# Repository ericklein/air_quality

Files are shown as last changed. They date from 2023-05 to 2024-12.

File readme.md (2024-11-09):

# Air Quality
AI: PUT HERO SHOT HERE

## Purpose
Air Quality, aka AQ, captures temperature, humidity, and if configured with the appropriate sensor, CO2 (carbon dioxide) values. If AQ is configured with a screen, it can display this information. If AQ is connected to WiFi, it can log this information to a number of network endpoints, and it displays local outdoor weather and air quality information to compliment the indoor sensor information.

AQ was created to determine if the CO2 level in the room was "good" and grew into a fuller featured room air quality monitor.

## Associated projects
AQ has a number of sibling projects that share common hardware and code attributes:
- [Powered Air Quality](https://github.com/ericklein/powered_air_quality) has all of the features of AQ along with the ability to sample local air particulate levels. This project uses an AC power source.
- [RCO2](https://github.com/ericklein/rco2) is a small, portable version of AQ that only samples and displays air quality levels.
- [Badge](https://github.com/ericklein/badge) is RCO2 in a badge form factor capable of displaying additional information beyond air quality levels.

## Features
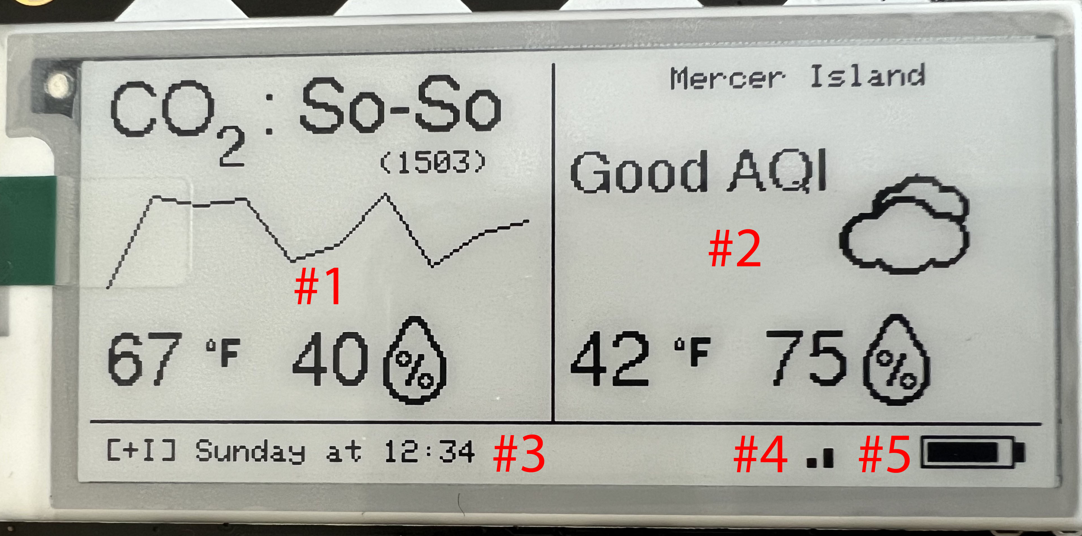
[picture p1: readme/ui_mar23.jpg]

### Indoor air quality information (#1)
- If available, displays the US standard CO2 label and value
- Displays the temperature and humidity
### Outside air quality information (#2)
- Uses OpenWeatherMap data, if available, to display
	- latest air quality information
	- current weather condition as icon
	- temperature and humidity levels
### Data publishing information (#3)
- displays the last time the screen information was updated.
- [+I] the indoor temperature, humidity, and CO2 information was successfully published to the defined InfluxDB server
- [+M] the indoor temperature, humidity, and CO2 information was successfully published to the defined MQTT broker
### WiFi signal strength (#4)
- based on RSSI
### Battery level (#5)

## Target configuration
- Set parameter configuration using config.h
- Private configuration settings including WiFi SSID/password and network endpoint credentials are contained in a `secrets.h` file that is not included in this repo.  Instead you'll find the file `secrets_template.h`, which should be copied to `secrets.h` and then edited to supply the right access credentials and configuration values to match your deployment environment.

## Bill of Materials (BOM)
### MCU
- [Adafruit MagTag](https://www.adafruit.com/product/4800)
- [Adafruit ESP32V2 Feather](https://www.adafruit.com/product/5400)
	- core code is fairly portable
### WiFi
- [Adafruit MagTag](https://www.adafruit.com/product/4800)
	- any ESP32
### Sensors
- [AHT20 temp/humidity sensor](https://www.adafruit.com/product/4566)
	- or similar AHT20 parts
- [BME280 temp/humidity sensor](https://www.adafruit.com/product/2652)
- [SCD40 temp/humidity/CO2 sensor](https://www.adafruit.com/product/5187)
	- SCD40 used in most of our build configurations
	- can use any SCD40 connected over i2c
### Battery
#### monitor
- [LC709203F battery voltage monitor](https://www.adafruit.com/product/4712)
- [GPIO pin on ESP32V2 Feather](https://www.adafruit.com/product/5400)
#### battery
- standard LiPo battery with JST 2-PH cable
### Screen
- [Adafruit MagTag (EPD)](https://www.adafruit.com/product/4800)
- [Adafruit 2.9" E-Ink Featherwing](https://www.adafruit.com/product/4777)
### Buttons/Switches
- [Adafruit MagTag](https://www.adafruit.com/product/4800)
	- on/off switch
### Pinouts
- SCD40
    - Stemma QT cable between MCU board and SCD40 board
        - or connect 3.3v/5v, GND, SDA, SCL on both sides
- LC709203F
    - Stemma QT cable between MCU board and SCD40 board
        - or connect 3.3v/5v, GND, SDA, SCL on both sides
## Supported network endpoints
### MQTT
- uncomment #define MQTT in config.h
- set appropriate parameters in config.h and secrets.h
	- Technical References
		- https://hackaday.com/2017/10/31/review-iot-data-logging-services-with-mqtt/
### Hassio MQTT
- AI: ADD DOCUMENTATION
### InfluxDB
- AI: ADD DOCUMENTATION
### DWEET
- AI: ADD DOCUMENTATION

## Issues and Feature Requests
- [Github Issues](https://github.com/ericklein/air_quality/issues)

## .plan (big ticket items)
- [WiFI Manager](https://github.com/tzapu/WiFiManager) support
- OTA firmware update support
- Change hardware to non ESP32S2 MCU, allowing multiple GPIO pin wakeup, which enables button presses to cycle through multiple information screens
## Supporting Material
### Screen
- Good Display SPI; GDEW029T5D 2.9" b/w 128x296, UC8151D 
- https://cdn-learn.adafruit.com/downloads/pdf/adafruit-gfx-graphics-library.pdf
### Battery
- [LC709203F datasheet](readme/LC709203F_datasheet.pdf)
### Temperature and Humdity
- [Ideal indoor humidity](https://iaq.works/humidity/indoor-humidity-level-why-is-the-40-60-range-ideal/)
### CO2 (Carbon Dioxide)
#### Scales
We currently use the following scale:
- <800 - Good
- 800-999 - So-So
- 1000+ - Poor
##### Alternate ideas
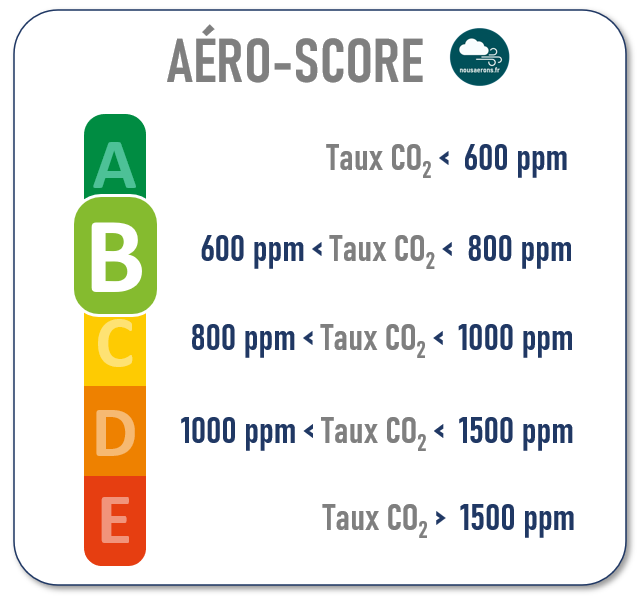
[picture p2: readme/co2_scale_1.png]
Example 1
- 
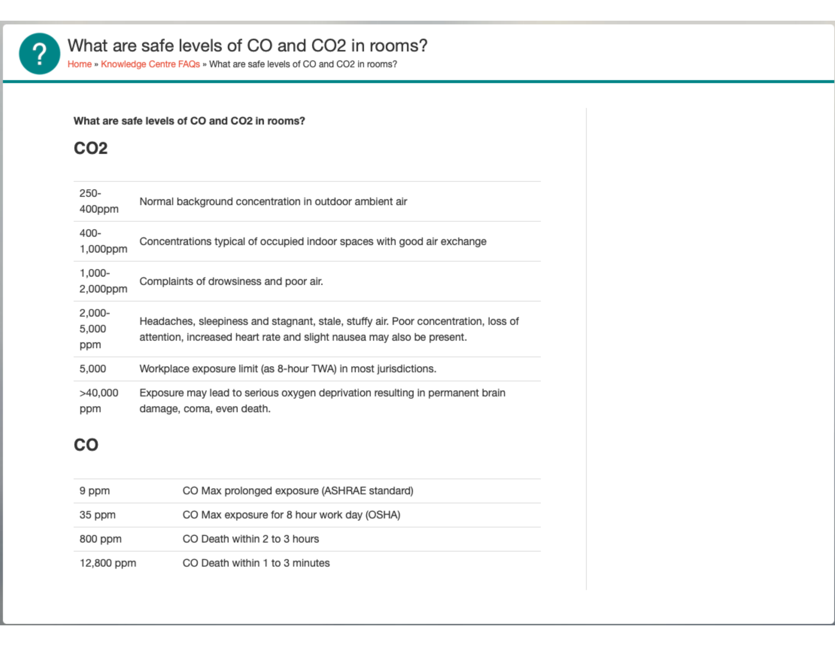
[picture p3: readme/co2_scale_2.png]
Example 2
- 
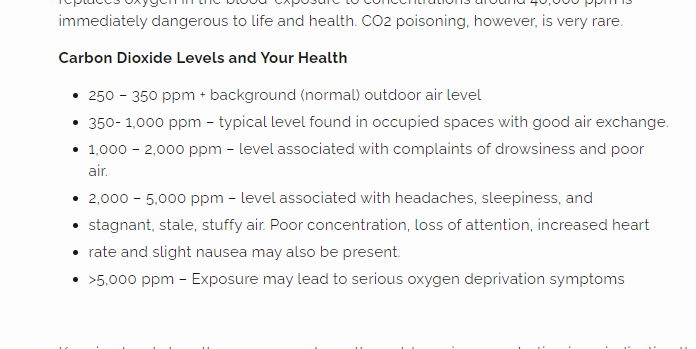
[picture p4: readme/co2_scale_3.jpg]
Example 3
- 
#### Impact on health
- [CO2 and indoor air quality](readme/CO2_and_indoor_air_quality.pdf)
#### Sensors
- [AHT20 info](https://learn.adafruit.com/adafruit-aht20)
- [CO2 sensor types](https://www.airgradient.com/blog/co2-sensors-photo-acoustic-vs-ndir-updated/)
- SCD40 sensor
	- [SCD40 datasheet](readme/Sensirion_CO2_Sensors_SCD4x_Datasheet.pdf)
### AQI
- [AQI Overview](readme/aqi_overview.md)
- [Open Weather Map Air Pollution API](https://openweathermap.org/api/air-pollution)
- [OSHA Air Quality](readme/OSHA_Indoor_Air_Quality.pdf)
- [Great site for air quality info](https://itsairborne.com/)
- [NYT on indoor gas stoves](https://www.nytimes.com/2023/01/29/climate/gas-stove-health.html)

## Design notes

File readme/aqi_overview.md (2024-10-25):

# Air Quality Index (AQI) overview
It's worth noting that while most people have heard of an "Air Quality Index" from their local weather service or news, the calculation of AQI from sensor readings is less well known.  Sensors measure and report particulate concentrations in various size ranges, the most widely used of which is "PM2.5", meaning airborne particulates of 2.5 microns in diameter or smaller, measured in micrograms per cubic meter.  
The more particulates measured the worse the air quality and, eventually, the greater the danger to humans and animals.  Howeveer, the perceived quality of the air and the risk from exposure vary in a non-obvious way based on the actual PM2.5 values observed.
That variability is what gave rise to the idea of an Air Quality Index in the first place, though as is often the case in associating health factors and risk with environmental data different governing bodies and standards organizations have put forward different ways of calculating risk from sensor data.  You can read much more about this in the Wikipedia page for [Air Quality](https://en.wikipedia.org/wiki/Air_quality_index).
In the US, the Environmental Protection Agency (EPA) developed its own AQI measure, dividing the normal range of measured particulates and pollutants into six categories indicating increased levels of health concerns.  An overall AQI value is calculated from a piecewise linear function, with scaling and transition points defined by the EPA.  More details on that math are shared in the Wikipedia page cited above, as well as this [post](https://forum.airnowtech.org/t/the-aqi-equation/169) on the AirNow tech forum.

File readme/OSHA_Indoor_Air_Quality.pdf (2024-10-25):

# Indoor Air Quality in Commercial and Institutional Buildings

OSHA 3430-04 2011

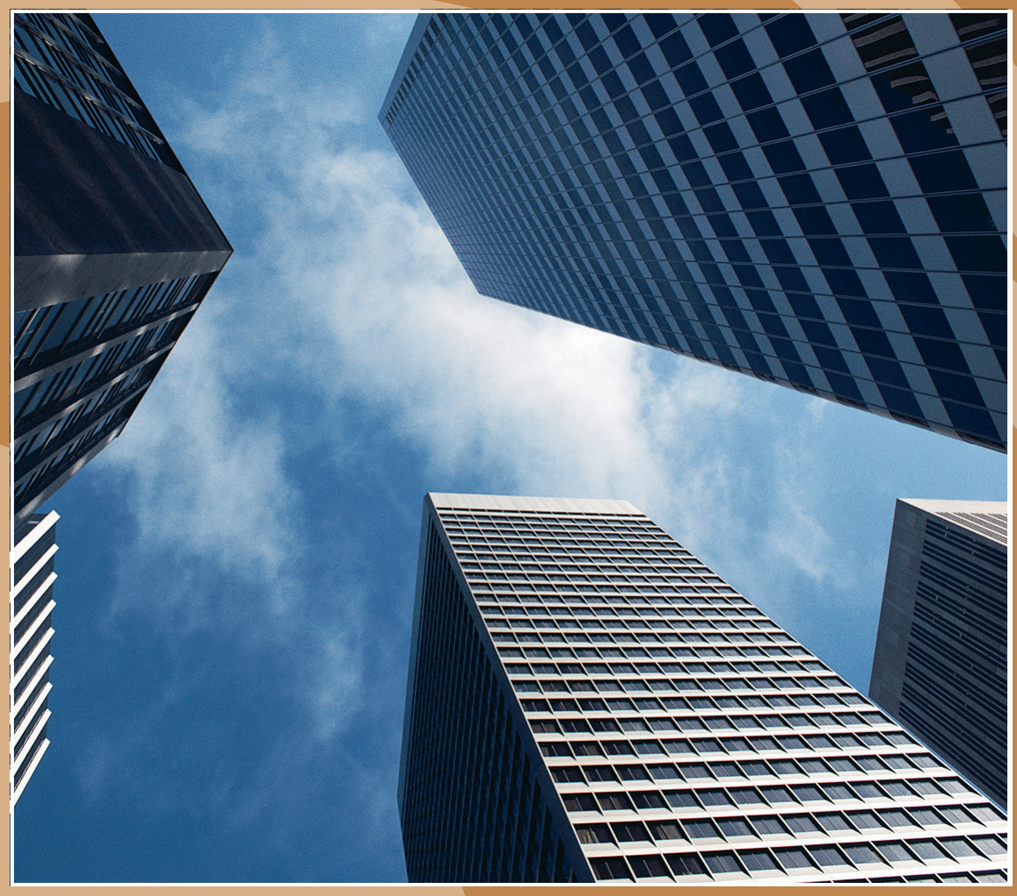
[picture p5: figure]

### Occupational Safety and Health Act of 1970

“To assure safe and healthful working conditions for working men and women; by authorizing enforcement of the standards developed under the Act; by assisting and encouraging the States in their efforts to assure safe and healthful working conditions; by providing for research, information, education, and training in the field of occupational safety and health.”

This publication provides a general overview of a particular standards-related topic. This publication does not alter or determine compliance responsibilities which are set forth in OSHA standards, and the Occupational Safety and Health Act of 1970. Moreover, because interpretations and enforcement policy may change over time, for additional guidance on OSHA compliance requirements, the reader should consult current administrative interpretations and decisions by the Occupational Safety and Health Review Commission and the courts.

Material contained in this publication is in the public domain and may be reproduced, fully or partially, without permission. Source credit is requested but not required.

This information will be made available to sensoryimpaired individuals upon request. Voice phone:
(202) 693-1999; teletypewriter (TTY) number: 1-877-889-5627.

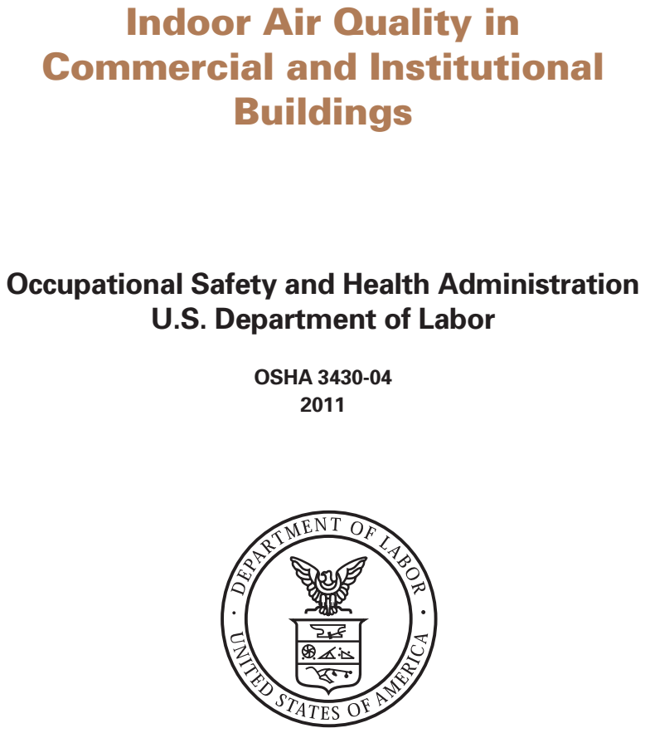
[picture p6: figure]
Indoor Air Quality in Commercial and Institutional Buildings; U.S. Department of Labor; OSHA 3430-04 2011

## Occupational Safety and Health Administration

The guidance is advisory in nature and informational in content. It is not a standard or regulation, and it neither creates new legal obligations nor alters existing obligations created by OSHA standards or the Occupational Safety and Health Act. Pursuant to the OSH Act, employers must comply with safety and health standards and regulations issued and enforced by either OSHA or by an OSHA-approved State Plan. In addition, the Act’s General Duty Clause, Section 5(a)(1), requires employers to provide their workers with a workplace free from recognized hazards likely to cause death or serious physical harm.

## Contents

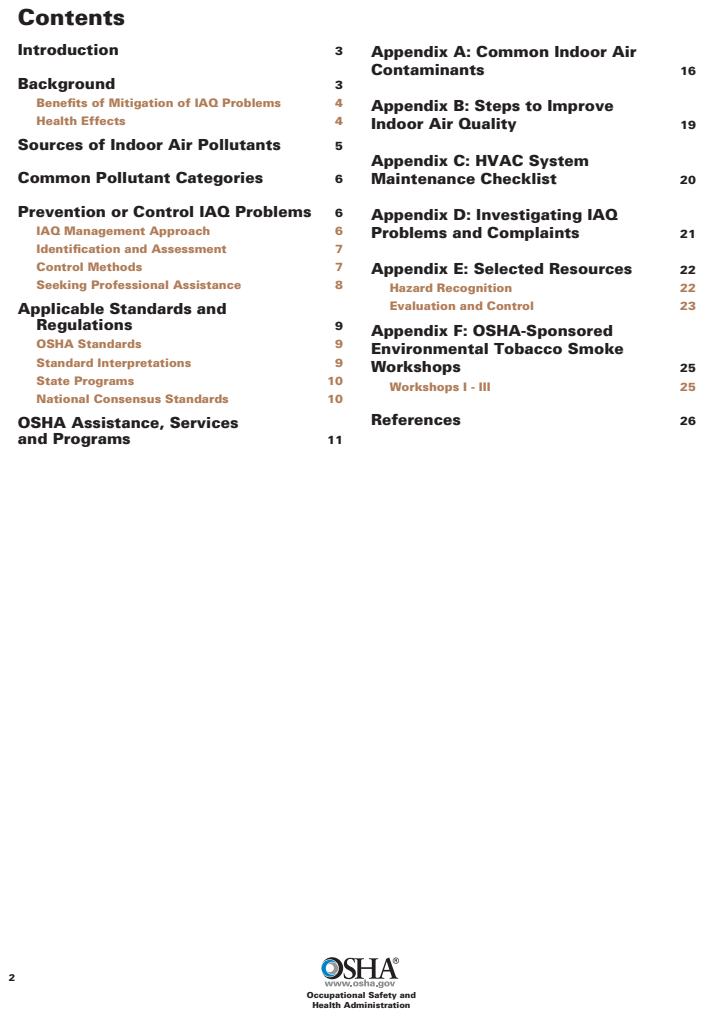
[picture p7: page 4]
Introduction; Background; Benefits of Mitigation of IAQ Problems; Health Effects; Sources of Indoor Air Pollutants; Common Pollutant Categories; Prevention or Control IAQ Problems; IAQ Management Approach; Identification and Assessment; Control Methods; Seeking Professional Assistance; Regulations; OSHA Standards; Standard Interpretations; State Programs; National Consensus Standards; and Programs; Contaminants; Indoor Air Quality; Maintenance Checklist; Problems and Complaints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

Applicable Standards and
OSHA Assistance, Services

Appendix A: Common Indoor Air

Appendix B: Steps to Improve

Appendix C: HVAC System

Appendix D: Investigating IAQ

Appendix F: OSHA-Sponsored
Environmental Tobacco Smoke

Occupational Safety and
Health Administration

INDOOR AIR QUALITY IN COMMERCIAL AND INSTITUTIONAL BUILDINGS | 3

## Introduction

Indoor air quality (IAQ) is a major concern to businesses, schools, building managers, tenants, and workers because it can impact the health, comfort, well-being, and productivity of the building occupants. OSHA recognizes that poor IAQ can be hazardous to workers’ health and that it is in the best interest of everyone that building owners, managers, and employers take a proactive approach to address IAQ concerns.

This OSHA guidance document on IAQ provides practical recommendations that will help prevent
or minimize IAQ problems in commercial and institutional buildings, and help resolve such problems quickly if they do arise. It provides flexible guidance to employers to help them keep their buildings free of pollutants or conditions that lead
to poor IAQ. It also provides information on good IAQ management, including control of airborne pollutants, introduction and distribution of adequate make-up air, and maintenance of an acceptable temperature and relative humidity. Temperature and humidity are important because thermal comfort underlies many complaints about “poor air quality.” Some of the information presented here has been derived from the Environmental Protection Agency’s (EPA) report, “An Office Building Occupant’s Guide to IAQ” (1)¹ and other documents listed in Appendix E, Selected Resources. The issue of environmental tobacco smoke will only be addressed in Appendix F, or indirectly in discussions of air quality relative to some possible components of tobacco smoke, e.g., carbon monoxide, carbon dioxide, particulates, etc. In 1998, OSHA conducted a series of three workshops on this issue and the proceedings of these workshops were published in 1999. See Appendix F for more information.

This document is directed primarily at employers, building owners and managers, and others responsible for building maintenance, but may also be used as a basic reference for all those involved in IAQ issues. Furthermore, information presented here can help with the decision of whether or not the services of an outside professional may be needed. The advice of a medical professional should always be sought if there are any immediate health issues. Contractors and other professionals (e.g., industrial hygienists or other environmental health and safety professionals) who respond to IAQ concerns, as well as members of the general public, may also find this information helpful.

## Background

IAQ has been identified by the EPA as one of the top five most urgent environmental risks to public health (2). The Centers for Disease Control and Prevention (CDC) estimates that the majority of Americans spend approximately 90 percent of their time indoors (3). On average, office workers spend approximately 40 hours a week in office buildings. These workers also study, eat, drink, and, in certain work settings, sleep in enclosed environments where make-up air (i.e., fresh air added to recirculated air) may be compromised. For this reason, some experts believe that more people may suffer from the effects of indoor air pollution than from outdoor air pollution.

Each building has its own set of circumstances. Air quality may be determined by the site of the building, its original design, renovations, whether air handling systems have been maintained, occupant densities, activities conducted within the building, and the occupants’ satisfaction with their environment. IAQ problems can arise from a single source or any combination of factors. Inadequate IAQ may begin with poor building design or failure of the building enclosure or envelope (roof, facade, foundation, etc.). Other issues may be associated with the location of the building and mixed uses of the building. Many common IAQ problems are associated with improperly operated and maintained heating, ventilating and air-conditioning (HVAC) systems, overcrowding, radon, moisture incursion and dampness, presence of outside air pollutants, and the presence of internally generated contaminants such as use of cleaning and disinfecting supplies and aerosol products, off-gassing from materials in the building, and use of mechanical equipment. Improper temperature and relative humidity conditions can also present problems, especially concerning comfort.

Many IAQ complaints are associated with flaws in building design and by inadequate routine preventive maintenance of building enclosures (envelopes), plumbing, and HVAC systems (2, 4, 5). To resolve many IAQ problems, a preventive maintenance program should be established based on the system’s recommended maintenance schedule outlined by the architect or engineer, the manufacturer, or an HVAC professional. Regular preventive maintenance not only ensures that systems are operating properly, but also can result in cost savings, improved operating efficiency, and
increased worker productivity (6). The U.S. Green ¹The numbers in parentheses refer to specific entries in the last section of this document titled “References.”

4

Research has linked building dampness with significant health effects. Numerous species of bacteria and fungi, in particular filamentous fungi (mold), can contribute significantly to indoor air pollution (4, 15-20). Whenever sufficient moisture is present within workplaces, these microbes can grow and affect the health of workers in several ways. Workers may develop respiratory symptoms, allergies, or asthma (8). Asthma, cough, wheezing, shortness of breath, sinus congestion, sneezing, nasal congestion, and sinusitis have all been associated with indoor dampness in numerous studies (21-23). Asthma is both caused by and worsened by dampness in buildings. The most effective means to prevent or minimize adverse health effects is to determine the sources of persistent dampness in the workplace and eliminate them. More details on preventing mold-related problems can be found in the OSHA publication titled: “Preventing Mold-Related Problems in the Indoor Workplace” (17). Other environmental factors such as poor lighting, stress, noise, and thermal discomfort may cause or contribute to these health effects (8).

Building Council (USGBC), among others, has demonstrated that IAQ issues can be readily and practically addressed when building systems are retrofitted for energy efficiency. (http://www.usgbc.org/
DisplayPage.aspx?CMSPageID=221#v2008)
Benefits of Mitigation of IAQ Problems Good IAQ in buildings is an important component of a healthy indoor environment. It contributes to a favorable and productive environment for building occupants, giving them a sense of comfort, health, and well-being. Significant increases in worker productivity have also been demonstrated when the air quality was adequate (6). Research has also shown that workers in buildings with adequate air quality have reduced rates of symptoms related to poor air quality (7).

Health Effects
Symptoms related to poor IAQ are varied depending on the type of contaminant. They can easily be mistaken for symptoms of other illnesses such as allergies, stress, colds, and influenza. The usual clue is that people feel ill while inside the building, and the symptoms go away shortly after leaving the building, or when away from the building for a period of time (such as on weekends or a vacation). Health or symptom surveys, such as the one included in Appendix D, have been used to help ascertain the existence of IAQ problems.

Failure of building owners and operators to respond quickly and effectively to IAQ problems can lead to numerous adverse health consequences. Health effects from indoor air pollutants may be experienced soon after exposure or, possibly, years later (8, 9, 10). Symptoms may include irritation of
the eyes, nose, and throat; headaches; dizziness; rashes; and muscle pain and fatigue (11, 12, 13, 14). Diseases linked to poor IAQ include asthma and hypersensitivity pneumonitis (11, 13). The specific pollutant, the concentration of exposure, and the frequency and duration of exposure are all important factors in the type and severity of health effects resulting from poor IAQ. Age and preexisting medical conditions such as asthma and allergies may also influence the severity of the effects. Long-term effects due to indoor air pollutants may include respiratory diseases, heart disease, and cancer, all of which can be severely debilitating or fatal (8, 11, 13).

INDOOR AIR QUALITY IN COMMERCIAL AND INSTITUTIONAL BUILDINGS | 5

Renovation Activities: When painting and other renovations are being conducted, dust or other by-products of the construction materials are sources of pollutants that may circulate through a building. Isolation by barriers and increased ventilation to dilute and remove the contaminants are recommended.

Local Exhaust Ventilation: Kitchens, laboratories, maintenance shops, parking garages, beauty and nail salons, toilet rooms, trash rooms, soiled laundry rooms, locker rooms, copy rooms and other specialized areas may be a source of pollutants when they lack adequate local exhaust ventilation.

Building Materials: Disturbing thermal insulation or sprayed-on acoustical material, or the presence of wet or damp structural surfaces (e.g., walls, ceilings) or non-structural surfaces (e.g., carpets, shades), may contribute to indoor air pollution.

Building Furnishings: Cabinetry or furniture made of certain pressed-wood products may release pollutants into the indoor air.

Building Maintenance: Workers in areas in which pesticides, cleaning products, or personal-care products are being applied may be exposed to pollutants. Allowing cleaned carpets to dry without active ventilation may promote microbial growth.

Occupant Activities: Building occupants may be the source of indoor air pollutants; such pollutants include perfumes or colognes.

## Sources of Indoor Air Pollutants

The relative importance of any single source depends on how much of a given pollutant it emits, how hazardous those emissions are, occupant proximity to the emission source, and the ability of the ventilation system (i.e., general or local) to remove the contaminant. In some cases, factors such as the age and maintenance history of the source are significant.

Sources of indoor air pollution may include:

Building Site or Location: The location of a building can have implications for indoor pollutants. Highways or busy thoroughfares may be sources of particulates and other pollutants in nearby buildings. Buildings sited on land where there was prior industrial use or where there is a high water table may result in leaching of water or chemical pollutants into the building.

Building Design: Design and construction flaws may contribute to indoor air pollution. Poor foundations, roofs, facades, and window and door openings may allow pollutant or water intrusion. Outside air intakes placed near sources where pollutants are drawn back into the building (e.g., idling vehicles, products of combustion, waste containers, etc.) or where building exhaust reenters into the building can be a constant source of pollutants. Buildings with multiple tenants may need an evaluation to ensure emissions from one tenant do not adversely affect another tenant.

Building Systems Design and Maintenance: When the HVAC system is not functioning properly for any reason, the building is often placed under negative pressure. In such cases, there may be infiltration of outdoor pollutants such as particulates, vehicle exhaust, humid air, parking garage contaminants, etc.

Also, when spaces are redesigned or renovated, the HVAC system may not be updated to accommodate the changes. For example, one floor of a building that housed computer services may be renovated for offices. The HVAC system would need to be modified for office employee occupancy (i.e., modifying temperature, relative humidity, and air flow).

6

## Prevention and Control of IAQ Problems

IAQ Management Approach
Ideally, an employer should use a systematic approach when addressing air quality in the workplace. The components of a systematic approach for addressing IAQ are the same as those for an overall safety and health program approach, and include management commitment, training, employee involvement, hazard identification and control, and program audit. Management needs to be receptive to potential concerns and complaints, and to train workers on how to identify and report air quality concerns. If employees express concerns, prompt and effective assessment and corrective action is the responsibility of management.

It is recommended that building owners/managers develop and implement an IAQ management plan to address, prevent, and resolve IAQ problems in their specific buildings. The EPA’s report, IAQ Tools for Office Buildings, provides a set of flexible and specific activities that can be useful to building owners/managers for developing such a plan. A key feature of the plan is the selection of an IAQ Coordinator. The role and functions of an IAQ Coordinator are described in Section 3 of the EPA’s report, IAQ Tools for Schools Action Kit (24). Other critical features of the plan include establishing necessary IAQ policies, assessing the current status of IAQ in buildings through periodic inspections, maintaining appropriate logs and checklists, performing necessary repairs and upgrades, and implementing follow-up assessments or other needed actions.

Employers who lease space should be familiar with the building management’s program and methods for mitigating or resolving indoor air quality problems. It is especially important for employers to know who to contact in buildings where there is mixed use and pollutants are emanating from other sources in the building. Employers should negotiate leases that specify IAQ performance criteria. For example, a lease should specify that the space be ventilated with outdoor air while occupied and at a rate described in ASHRAE 62.1 Ventilation for Acceptable Indoor Air Quality.

An important management strategy is to foster a team approach for problem solving and consensus building. The IAQ Team should include, but not necessarily be limited to, building occupants, administrative staff, facility operators, custodians, building healthcare staff, contract service providers, and other interested parties.

## Common Pollutant Categories

Although there are numerous indoor air pollutants that can be spread through a building, they typically fall into three basic categories: biological, chemical, and particle (1).

Biological
Excessive concentrations of bacteria, viruses, fungi, dust mites, animal dander, and pollen may result from inadequate maintenance and housekeeping, water spills, inadequate humidity control, condensation, or water intrusion through leaks in the building envelope or flooding.

Chemical
Sources of chemical pollutants (gases and vapors) include emissions from products used in the building (e.g., office equipment; furniture, wall and floor coverings; pesticides; and cleaning and consumer products), accidental spills of chemicals, products used during construction activities such as adhesives and paints, and gases such as carbon monoxide, formaldehyde, and nitrogen dioxide, which are products of combustion.

Particle (Non-biological)
Particles are solid or liquid, non-biological, substances that are light enough to be suspended in the air. Dust, dirt, or other substances may be drawn into the building from outside. Particles can also be produced by activities that occur in buildings such as construction, sanding wood or drywall, printing, copying, and operating equipment.

Some of the most common indoor air pollutants, and the means to control or prevent them, are discussed in Appendix A.

INDOOR AIR QUALITY IN COMMERCIAL AND INSTITUTIONAL BUILDINGS | 7

the effectiveness of ventilation (5, 26), and excessive population density (e.g., overcrowding).
- Ensure that good housekeeping practices are being applied.
- Ensure that routine preventive maintenance and upkeep of buildings is being performed. A preventive maintenance program provides the care to all building systems and components that keeps them operating at peak performance according to manufacturer’s specifications, and also allows for early detection of problems
(1, 18).
- Ensure that scheduled renovations are isolated from the building’s general dilution ventilation system when occupants are in the building. Control Methods
There are three basic control methods for lowering concentrations of indoor air pollutants:

### 1. Source management

Source management includes removal, substitution, and enclosure of sources. It is the most effective control method when it can be applied practically. For example, the U.S. Consumer Product Safety Commission recommends installing carpets that are low-volatile organic compound (VOC) emitters, and encourages consumers to ask retailers or installers about the carpet industry’s voluntary “green label” program for new carpets (27). According to the carpet industry, the green and white logo displayed on carpet samples informs the consumer that the specific manufacturer’s product has been tested by an independent laboratory and has met the criteria for very low emissions (28). The label, however,
is not a guarantee that the carpet will not cause health problems (27). Another example is that the employer can set up temporary barriers or place the space under negative pressure relative to adjoining areas to contain the pollutants during construction activities.

### 2. Engineering controls

a. Local exhaust
Local exhaust, such as a canopy hood, is very effective in removing point sources of pollutants before they can be dispersed into the building’s indoor air.
b. General dilution ventilation
General dilution ventilation systems, when properly designed, operated, and maintained, will control normal amounts of air pollutants.
A well-designed and functioning HVAC system controls temperature and relative humidity levels

Lastly, following up with affected personnel will serve to validate the effectiveness of the mitigation activities. For more information about the IAQ management approach, refer to OSHA’s Safety and Health Topics Page on Injury and Illness Prevention Programs. (http://www.osha.gov/dsg/topics/safetyhealth/index.html).
Identification and Assessment
Methods used in an IAQ investigation may include identifying pollutant sources, evaluating the HVAC system performance, observing production processes and work practices, measuring contamination levels and employee exposures, providing medical testing or physical examinations, conducting employee interviews, and reviewing records of medical tests, job histories, and injuries and illnesses. The Appendices provide resources and checklists that building owners, managers, and occupants can use to investigate IAQ complaints, document walkthrough inspections, and correct IAQ problems.

To prevent IAQ problems effectively and efficiently, building managers should know and understand the history of the building (construction, uses, maintenance, etc.). If possible, owners and managers should maintain blueprints and construction documents, including information about any renovations of the building.

Some important practices include:
- Inspect and assess the building envelope, including the roof, walls, and foundation, and promptly respond to identified problems. Routinely check the building for water leaks, seals around doors and windows, and any visible damp or moist parts of the building. Clean and dry any damp or wet building materials and furnishings within 24 to 48 hours after detection to prevent the growth of mold.
- Ensure and validate that the building is maintained under a slight positive pressure (i.e., air comes out of the building when exterior doors are opened).
- Check whether the temperature and humidity are maintained in a recommended comfort range (temperature: 68 to 78 degrees and relative humidity: 30% to 60%) (25).
- Ensure that routine maintenance of the HVAC system is being performed, including the performance of the system bringing outdoor air into the building. (1).
- Monitor carbon dioxide (CO2) levels. The carbon dioxide levels can be used as a rough indicator of

8

storing food properly, and choosing cleaning products and methods that minimize the introduction of pollutants into the building (18). These steps are outlined in Appendix B. Seeking Professional Assistance
Some indoor air problems can be resolved when good practices are put in place to control contaminants and building personnel follow good housekeeping approaches. Other problems may be difficult to resolve, however, and may require outside assistance. A building owner or manager may first want to consult local, state, or federal government agencies (e.g., education, health, environmental protection, or agriculture agencies) for assistance or direction in solving IAQ problems. These governmental agencies may be able to help an employer identify the types of experts who could best assist them.

Examples of experts include:
- Structural engineers - address issues with structural elements such as corrosion problems in a building’s foundation;
- Architects - responsible for designing the building envelope and can mitigate water intrusion problems by designing vapor barriers;
- Mechanical engineers - test and balance HVAC systems and may be able to assess and recommend repairs/replacement of HVAC systems and local exhaust ventilation systems; and
- Industrial hygienists - assess general IAQ parameters such as air changes in a building, carbon dioxide levels, carbon monoxide levels, and other indoor pollutants, and also evaluate contaminant levels.

There may be private firms or consultants in your area with experience in IAQ work. Such firms may be found in general resources such as a telephone directory (e.g., under “Engineers,” “Environmental and Ecological Services,” “Laboratories-Testing,” or “Industrial Hygiene Consultants”), on the Internet, or by asking building owners/managers for referrals. Some professionals who work with IAQ issues must meet licensing and certification requirements to practice in their disciplines. A consultant should base any testing recommendations or protocol on a thorough visual inspection, walkaround, and interviews with building occupants.

to provide thermal comfort, distributes adequate amounts of outdoor air to meet the ventilation needs of building occupants, and also dilutes and removes odors and other contaminants. Testing and rebalancing of HVAC systems are essential when partitions are moved in buildings. Appendix C contains an HVAC System Maintenance Checklist that can be used to assist in routine maintenance of the HVAC system. For certain situations, such as painting and carpet cleaning, temporarily increasing ventilation can help dilute the concentration of vapors in the air.
c. Air cleaning
Air cleaning primarily involves the removal of particles from the air as the air passes through the HVAC equipment. Most HVAC system filtration is provided to keep dirt off of coil surfaces to promote heat transfer efficiency. Most smudging observed around air supply diffusers in a ceiling result from entrainment (trapping) of dirt particles in the space that accumulate there because of poor housekeeping.

### 3. Administrative controls

a. Work Schedule
Through scheduling, managers can significantly reduce the amount of pollutant exposure in their buildings. For instance:
1. Eliminate or reduce the amount of time a worker is exposed to a pollutant (i.e., scheduling maintenance or cleaning work to be accomplished when other building occupants are not present).
2. Reduce the amount of chemicals being used by or near workers (i.e., limit the amount of chemicals being used by the worker during maintenance or cleaning activities).
3. Control the location of chemical use (i.e., perform maintenance work on moveable equipment in a maintenance shop as opposed to the general area, or locate the equipment (e.g., printers, copiers) in a separate room).
b. Education
Education of building occupants regarding IAQ is important (29). If occupants are provided with information about the sources and effects of pollutants under their control, and about the proper operation of the ventilation system, they can alert their employer and/or take action to reduce their personal exposure.
c. Housekeeping
Housekeeping practices should include preventing dirt from entering the environment (using, for example, walk-off mat systems), removing dirt once it is in the building, disposing of garbage,

INDOOR AIR QUALITY IN COMMERCIAL AND INSTITUTIONAL BUILDINGS | 9

## Applicable Standards and Regulations

OSHA does not have a general IAQ standard, but does provide guidelines addressing the most common workplace complaints about IAQ, which are typically related to temperature, humidity, lack of outside air ventilation, or smoking. OSHA standards address potential hazardous conditions leading to serious physical harm or death. Such standards may include those for specific air contaminants, ventilation systems, or the General Duty Clause of the Occupational Safety and Health Act of 1970 (OSH Act). This section highlights OSHA standards, standards interpretations (official OSHA letters of interpretation of its standards), and national consensus standards related to IAQ.

OSHA Standards
All OSHA regulations, interpretations, and the OSH Act can be found on www.osha.gov. Important OSHA statues and standards include:
- Occupational Safety and Health Act of 1970
Section 5(a)(1), often referred to as the General Duty Clause, requires employers to “furnish to each of his employees employment and a place of employment which are free from recognized hazards that are causing or are likely to cause death or serious physical harm to his employees.”
Section 5(a)(2) requires employers to “comply with occupational safety and health standards promulgated under this Act.”
Some of the applicable OSHA Standards are:
- 29 CFR 1904, Recording and Reporting Occupational Injuries and Illnesses.
- 29 CFR 1910.94, Ventilation.
- 29 CFR 1910.1000, Air Contaminants.
- 29 CFR 1910.1048, Formaldehyde.
- 29 CFR 1910.1450, Occupational exposure to hazardous chemicals in laboratories.

Standard Interpretations
- Enforcement policy for respiratory hazards not covered by OSHA Permissible Exposure Limits. (January 24, 2003.) https://www.osha.gov/pls/oshaweb/owadisp.show_document?p_table=INTERPRETA-TIONS&p_id=24749.
- Air monitoring results, citations, and employee exposure records. (March 27, 2002.) https://www.osha.gov/pls/oshaweb/owadisp.show_document?p_table=INTERPRETATIONS&p_id=24261.
- The use of ozone gas from ozone generators in a large room. (April 3, 1995.) https://www.osha.gov/pls/oshaweb/owadisp.show_document?p_table=INTERPRETATIONS&p_id=21753.
- Request for a list of all OSHA-regulated air contaminants. (March 22, 1995.) https://www.osha.gov/pls/oshaweb/owadisp.show_document?p_table=INTERPRETATIONS&p_id=21731.
- Record retention requirements for indoor air quality documents and reports. (August 1, 2002.) http://www.osha.gov/pls/oshaweb/owadisp.show_document?p_table=INTERPRETATIONS&p_id=24255.
- Reiteration of existing OSHA policy on indoor air quality: office temperature and environmental tobacco smoke. (February 23, 2003.) http://www.osha.gov/pls/oshaweb/owadisp.show_document?p_table=IN-TERPRETATIONS&p_id=24602.

10

State Programs
The Occupational Safety and Health Act of 1970 (OSH Act) encourages states to develop and operate their own job safety and health plans. States with plans approved and monitored by OSHA under section 18(b) of the OSH Act must adopt standards and enforce requirements that are at least as effective as federal requirements. There are currently 27 State Plan states and territories: Twenty-two of these states and territories administer plans covering both private and public (state/territory and local government) workers; the other plans, Connecticut, Illinois, New Jersey, New York, and the Virgin Islands, cover public-sector workers only.

Additional information on State Plans may be found at http://www.osha.gov/dcsp/osp/index.html.

For the most part, these OSHA-approved State Plans adopt standards that are identical to the federal OSHA standards. However, some states have adopted state-specific standards that are at least as effective as the Federal OSHA standards, including the New Jersey IAQ standard. The New Jersey IAQ standard, (N.J.A.C. 12:100-13; 2007) sets standards for indoor air quality in existing buildings occupied by public employees during their regular working hours.

State of California IAQ Program. (http://www.cal-iaq.org/about-us/about-cal-iaq)

This program is a part of the California Department of Public Health (CDPH), separate from the State OSHA program. The purpose of the California IAQ program is to conduct and promote the coordination of research, investigations, experiments, demonstrations, surveys, and studies relating to the causes, effects, extent, prevention, and control of indoor pollution in California.

National Consensus Standards
Note: These are NOT OSHA regulations. However, they do provide guidance from their originating organizations related to worker protection.
American National Standards Institute (ANSI)/American Society of Heating, Refrigerating, and Air Conditioning Engineers (ASHRAE).
- 62.1-2010, Ventilation for Acceptable Indoor Air Quality. This standard specifies recommended outdoor air ventilation rates. The recommended outdoor ventilation rates are based on olfactory studies, and acceptable indoor air quality is met when 80% or more of the exposed people do not express dissatisfaction. Whereas ASHRAE Standard 62 has always been considered a design standard for ventilation, building owner/operators should pay particular attention to Section 8 titled Operations and Maintenance. Section 8 offers guidance to the building owner/operator as to what outdoor air ventilation components should be maintained, what tasks should be performed, and the minimum frequency for performing those tasks.
- 55-2010, Thermal Environmental Conditions for Human Occupancy. Specifies temperatures that approximately 80 percent of building occupants should find acceptable.
American Society for Testing and Materials (ASTM).
- E1971–05, Standard Guide for Stewardship for the Cleaning of Commercial and Institutional Buildings.

INDOOR AIR QUALITY IN COMMERCIAL AND INSTITUTIONAL BUILDINGS | 11

Each year, responding to requests from small employers looking to create or improve their safety and health management programs, OSHA’s On-site Consultation Program conducts over 29,000 visits to small business worksites covering over 1.5 million workers across the nation.

On-site consultation services are separate from enforcement and do not result in penalties or citations. Consultants from state agencies or universities work with employers to identify workplace hazards, provide advice on compliance with OSHA standards, and assist in establishing safety and health management programs.

For more information, to find the local
On-site Consultation office in your state, or to request a brochure on Consultation Services, visit www.osha.gov/consultation, or call 1-800-321-OSHA [6742].

Under the consultation program, certain exemplary employers may request participation in OSHA’s Safety and Health Achievement Recognition Program (SHARP). Eligibility for participation includes, but is not limited to, receiving a full-service, comprehensive consultation visit, correcting all identified hazards and developing an effective safety and health management program. Worksites that receive SHARP recognition are exempt from programmed inspections during the period that the SHARP certification is valid.

Cooperative Programs
OSHA offers cooperative programs under which businesses, labor groups and other organizations can work cooperatively with OSHA. To find out more about any of the following programs, visit www.osha.gov/dcsp/compliance_assistance/index_ programs.html.

Alliance Program
Through the Alliance Program, OSHA works with groups committed to worker safety and health to prevent workplace fatalities, injuries and illnesses. These groups include trade or professional organizations, employers, unions, consulates, faithbased and community-based organizations and educational institutions. OSHA and the groups work together to develop compliance assistance tools and resources, share information with workers and employers, and educate workers and employers about their rights and responsibilities.

## OSHA Assistance, Services and Programs

OSHA offers free compliance assistance to employers and workers. Several OSHA programs and services can help employers identify and correct job hazards, as well as improve their injury and illness prevention program.

Establishing an Injury and Illness Prevention Program
The key to a safe and healthful work environment is a comprehensive injury and illness prevention program.

Injury and illness prevention programs are systems that can substantially reduce the number and severity of workplace injuries and illnesses, while reducing costs to employers. Thousands of employers across the United States already manage safety using illness and injury prevention programs, and OSHA believes that all employers can and should do the same. Thirty-four states have requirements or voluntary guidelines for workplace injury and illness prevention programs. Most successful injury and illness prevention programs are based on a common set of key elements. These include management leadership, worker participation, hazard identification, hazard prevention and control, education and training, and program evaluation and improvement. Visit OSHA’s illness and injury prevention program web page at www.osha.gov/dsg/topics/safetyhealth for more information.

Compliance Assistance Specialists
OSHA has compliance assistance specialists throughout the nation located in most OSHA offices. Compliance assistance specialists can provide information to employers and workers about OSHA standards, short educational programs on specific hazards or OSHA rights and responsibilities, and information on additional compliance assistance resources. For more details, visit www.osha.gov/ dcsp/compliance_assistance/cas.html or call 1-800-321-OSHA [6742] to contact your local OSHA office.

Free On-site Safety and Health Consultation Services for Small Business OSHA’s On-site Consultation Program offers free and confidential advice to small and medium-sized businesses in all states across the country, with priority given to high-hazard worksites.

12

For more information on training, contact the
OSHA Directorate of Training and Education, 2020 Arlington Heights Road, Arlington Heights, IL 60005; call 1-847-297-4810; or visit www.osha.gov.

Susan Harwood Training Grants
OSHA awards grants to nonprofit organizations to provide workers and small employers with safety and health training and education about hazard identification and prevention. Grants focus on small business, hard-to-reach workers and high-hazard industries.

Grantees develop programs that address safety and health topics selected by OSHA, recruit workers and employers for the training and conduct the training. They are also expected to follow up with students to find out how they have applied the training in their workplaces.

For more information on training grants, contact the OSHA Directorate of Training and Education by calling 1-847-297-4810 or visiting www.osha.gov.

OSHA Educational Materials
OSHA has many types of educational materials in English, Spanish, Vietnamese and other languages available in print or online. These include:
- Brochures/booklets that cover a wide variety of job hazards and other topics;
- Fact Sheets, which contain basic backgroundinformation on safety and health hazards;
- Guidance documents that provide detailed examinations of specific safety and health issues;
- Online Safety and Health Topics pages;
- Posters;
- Small, laminated QuickCards™ that provide brief safety and health information; and
- QuickTakes, OSHA’s free, twice-monthly online newsletter with the latest news about OSHA initiatives and products to assist employers and workers in finding and preventing workplace hazards. To sign up for QuickTakes visit OSHA’s website at www.osha.gov and click on Quick-Takes at the top of the page.

To view materials available online or for a listing of free publications, visit OSHA’s website at www. osha.gov. You can also call 1-800-321-OSHA [6742] to order publications.

OSHA Strategic Partnership Program (OSPP) The OSPP provides the opportunity for OSHA to partner with employers, workers, professional or trade associations, labor organizations, and/or other interested stakeholders. OSHA Strategic Partnerships (OSP) are formalized through unique agreements designed to encourage, assist, and recognize partner efforts to eliminate serious hazards and achieve model workplace safety and health practices.

Challenge Program
OSHA Challenge provides interested employers and workers the opportunity to gain assistance in improving their safety and health management programs. OSHA Challenge is available to general industry, maritime and construction employers in the private and public sectors under OSHA’s federal jurisdiction.

Voluntary Protection Programs (VPP)
The VPP recognize employers and workers in private industry and federal agencies who have implemented effective safety and health management programs and maintain injury and illness rates below the national average for their respective industries. In VPP, management, labor, and OSHA work cooperatively and proactively to prevent fatalities, injuries, and illnesses through a system focused on: hazard prevention and control, worksite analysis, training, and management commitment and worker involvement. To participate, employers must submit an application to OSHA and undergo a rigorous on-site evaluation by a team of safety and health professionals. Union support is required for applicants who are represented by a bargaining unit. VPP participants are re-evaluated every three to five years to remain in the programs. VPP participants are exempt from OSHA programmed inspections while they maintain their VPP status.

Occupational Safety and Health Training
The OSHA Training Institute in Arlington Heights, Illinois, provides basic and advanced training and education in safety and health for federal and state compliance officers, state consultants, other federal agency personnel and private sector employers, workers, and their representatives.

In addition, 25 OSHA Training Institute Education Centers at 44 locations throughout the United States deliver courses on OSHA standards and occupational safety and health issues to thousands of students a year.

INDOOR AIR QUALITY IN COMMERCIAL AND INSTITUTIONAL BUILDINGS | 13

the workplace through its Health Hazard Evaluation (HHE) Program.

Workers, union representatives and employers can request a NIOSH HHE. An HHE is often requested when there is a higher than expected rate of a disease or injury in a group of workers. These situations may be the result of an unknown cause, a new hazard, or a mixture of sources. To request a NIOSH Health Hazard Evaluation go to www.cdc. gov/niosh/hhe/request.html. To find out more about the Health Hazard Evaluation Program:

- Call (513) 841-4382, or to talk to a staff member in Spanish, call (513) 841-4439; or
- Send an email to HHERequestHelp@cdc.gov.

OSHA’s website also has a variety of eTools. These include utilities such as expert advisors, electronic compliance assistance, videos and other information for employers and workers. To learn more about OSHA’s safety and health tools online, visit www.osha.gov.

## NIOSH Health Hazard Evaluation Program

Getting Help with Health Hazards
The National Institute for Occupational Safety and Health (NIOSH) is a federal agency that conducts scientific and medical research on workers’ safety and health. At no cost to employers or workers, NIOSH can help identify health hazards and recommend ways to reduce or eliminate those hazards in

14

OSHA Regional Offices

Region I
Boston Regional Office
(CT*, ME, MA, NH, RI, VT*)
JFK Federal Building, Room E340 Boston, MA 02203
(617) 565-9860 (617) 565-9827 FAX

Region II
New York Regional Office
(NJ*, NY*, PR*, VI*)
201 Varick Street, Room 670
New York, NY 10014
(212) 337-2378 (212) 337-2371 FAX

Region III
Philadelphia Regional Office
(DE, DC, MD*, PA, VA*, WV)
The Curtis Center
170 S. Independence Mall West Suite 740 West
Philadelphia, PA 19106-3309
(215) 861-4900 (215) 861-4904 FAX

Region IV
Atlanta Regional Office
(AL, FL, GA, KY*, MS, NC*, SC*, TN*) 61 Forsyth Street, SW, Room 6T50 Atlanta, GA 30303
(678) 237-0400 (678) 237-0447 FAX

Region V
Chicago Regional Office
(IL*, IN*, MI*, MN*, OH, WI)
230 South Dearborn Street
Room 3244
Chicago, IL 60604
(312) 353-2220 (312) 353-7774 FAX

Region VI
Dallas Regional Office
(AR, LA, NM*, OK, TX)
525 Griffin Street, Room 602 Dallas, TX 75202
(972) 850-4145 (972) 850-4149 FAX
(972) 850-4150 FSO FAX

Region VII
Kansas City Regional Office (IA*, KS, MO, NE)
Two Pershing Square Building 2300 Main Street, Suite 1010 Kansas City, MO 64108-2416
(816) 283-8745 (816) 283-0547 FAX

Region VIII
Denver Regional Office
(CO, MT, ND, SD, UT*, WY*) Cesar Chavez Memorial Building 1244 Speer Boulevard, Suite 551 Denver, CO 80204
(720) 264-6550 (720) 264-6585 Fax

Region IX
San Francisco Regional Office
(AZ*, CA*, HI*, NV*, and American Samoa, Guam and the Northern Mariana Islands) 90 7th Street, Suite 18100
San Francisco, CA 94103
(415) 625-2547 (415) 625-2534 FAX

Region X
Seattle Regional Office
(AK*, ID, OR*, WA*)
1111 Third Avenue, Suite 715
Seattle, WA 98101-3212
(206) 553-5930 (206) 553-6499 FAX

*These states and territories operate their own OSHA-approved job safety and health plans and cover state and local government employees as well as private sector employees. The Connecticut, Illinois, New Jersey, New York and Virgin Islands programs cover public employees only. (Private sector workers in these states are covered by Federal OSHA). States with approved programs must have standards that are identical to, or at least as effective as, the Federal OSHA standards.
Note: To get contact information for OSHA area offices, OSHA-approved state plans and OSHA consultation projects, please visit us online at www. osha.gov or call us at 1-800-321-OSHA (6742).

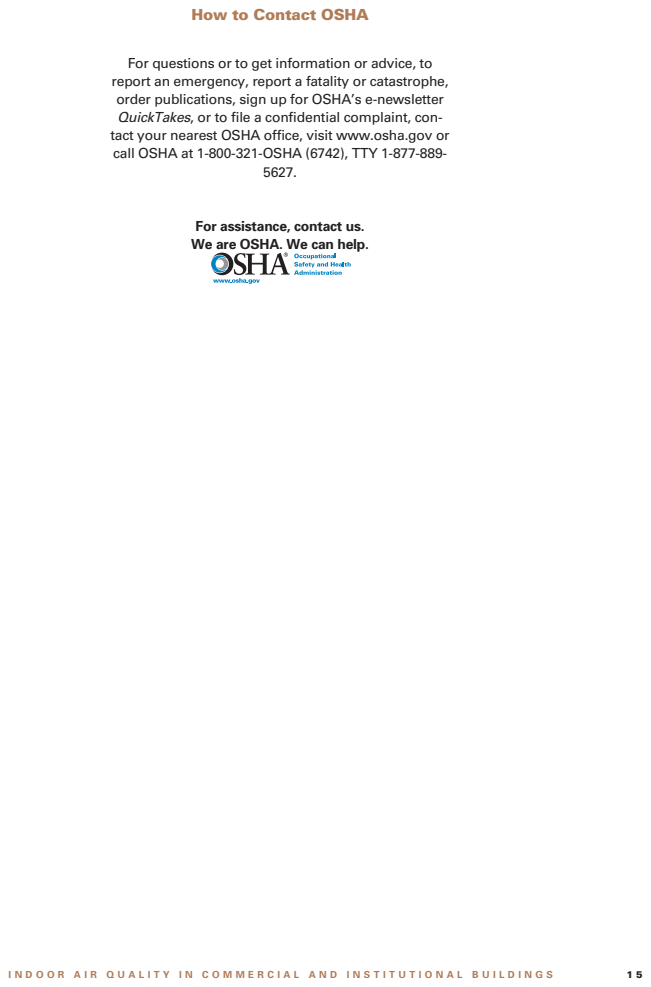
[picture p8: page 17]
INDOOR AIR QUALITY IN COMMERCIAL AND INSTITUTIONAL BUILDINGS

How to Contact OSHA

For questions or to get information or advice, to
report an emergency, report a fatality or catastrophe,
order publications, sign up for OSHA’s e-newsletter
QuickTakes, or to file a confidential complaint, con-
tact your nearest OSHA office, visit www.osha.gov or
call OSHA at 1-800-321-OSHA (6742), TTY 1-877-889-

For assistance, contact us.
We are OSHA. We can help.

16

Carbon dioxide (CO2)
CO2 is a colorless, odorless, and tasteless gas (36). It is a product of completed carbon combustion and the by-product of biological respiration. ASHRAE states that CO2 concentrations in acceptable outdoor air typically range from 300-500 ppm. Adverse health effects from CO2 may occur since it is an asphyxiant gas. At concentrations above 15,000 ppm, some loss of mental acuity has been noted (36). The OSHA PEL is 5,000 ppm as an 8-hour TWA. The CO2 levels can be used as a rough indicator of the effectiveness of ventilation (26), and excessive population density in a structure. CO2 increases in buildings with higher occupant densities, and is diluted and removed from buildings based on outdoor air ventilation rates. Therefore, examining levels of CO2 in indoor air can reveal information regarding occupant densities and outdoor air ventilation rates. High CO2 levels may indicate a problem with overcrowding or inadequate outdoor air ventilation rates.

Carbon Dioxide Poisoning – Symptoms
CO2, a by-product of normal cell function, is removed from the body via the lungs in the exhaled air. Exposure to high levels of CO2 can increase the amount of this gas in the blood, which is referred to as hypercapnia or hypercarbia. As the severity of hypercapnia increases, more symptoms ranging from headache to unconsciousness appear, and it can also lead to death (36, 37).

Pesticides
Pesticides are any substances or mixture of substances used for preventing, destroying, repelling, or mitigating any pest. These substances include insecticides, herbicides, fungicides, and various other substances used to control pests. Pesticides can cause harm to humans, animals, and the environment because they are designed to kill or otherwise adversely affect living organisms. Pesticides can also kill potential disease-causing organisms (8, 38).

Pesticide Poisoning Symptoms
Symptoms of pesticide poisoning depend heavily on the pesticide to which the worker was exposed. Symptoms often appear within minutes of pesticide exposure, but may take much longer to develop. The most common symptoms include headache, tears in the eyes, vomiting, sweating, and general weakness. Exposure to high doses may cause seizures and death.

## Appendix A: Common Indoor Air Contaminants

The purpose of this section is to provide additional information about several common indoor air contaminants.

Carbon monoxide (CO)
CO is a colorless, odorless gas produced by the incomplete burning of material containing carbon. CO poisoning² can cause brain damage and death. Common sources of CO are leaking vented combustion appliances, automobile exhaust, parking garages, etc. When not properly ventilated, emitted CO can build up. Employees exposed to low levels of CO may feel sick with headache and nausea, and will feel better when exposed to fresh air outside. However, their symptoms will recur shortly after returning to their workplace if CO is not eliminated.

CO Poisoning Symptoms
Poisoning due to low levels of CO can be confused with influenza symptoms, food poisoning, or other illnesses, and can be a long-term health risk if left unattended. Some of the symptoms of low-level CO poisoning are shortness of breath, mild nausea, and mild headaches (30-35).

Prolonged exposure to high levels of CO can lead to brain damage and even death. Adequate ventilation is an important control measure. The OSHA Permissible Exposure Limit (PEL) for CO is 50 parts per million (ppm) as an 8-hour time-weighted average (TWA); the National Institute for Occupational Safety and Health has a Recommended Exposure Limit (REL) of 35 ppm as a 10-hour TWA. According to the American Conference of Governmental Industrial Hygienists (ACGIH), the threshold limit value for CO is 25 ppm as an 8-hour TWA.

Carbon Monoxide Detectors
In addition to having a professional inspect appliances and furnaces, commercially available carbon monoxide detectors can be used to monitor the levels of carbon monoxide in buildings throughout the year. The manufacturer’s instructions on placement and maintenance should be followed.

2CO is a chemical asphyxiant; it displaces O2 in the blood, thereby suffocating the person exposed.

INDOOR AIR QUALITY IN COMMERCIAL AND INSTITUTIONAL BUILDINGS | 17

Small dust particles may remain airborne for long periods, while large particles settle more quickly. However, particles that have settled may be easily resuspended in the ambient air by currents of air or other disturbances. Drapery, carpet and other places where dust collects can harbor these contaminants; dirty cooling coils, humidifiers, condensate drains, and ductwork can incubate bacteria and molds. Areas with high humidity can accelerate their growth.

The most common sources of biological air contaminants are moisture-laden areas that support the growth of mold and bacteria present in the air (8, 16, 19, 44). Also, wet surfaces can provide a breeding ground for insects such as dust mites.

Moisture-induced microbial growth can result from water leaks and/or by condensation due to high humidity. Persistent dampness and microbial growth on interior surfaces and in building structures should be avoided or minimized as they may lead to adverse health effects (15). Common sources of moisture in buildings include: plumbing; roof and window leaks; flooding; condensation on cold surfaces, e.g., pipe sweating; poorly maintained drain pans; and wet foundations caused by landscaping or gutters that direct water into or under the building. Water vapor from unvented or poorly vented kitchens, showers, combustion appliances, or steam pipes can also create conditions that promote microbial growth. The most effective means to prevent or minimize adverse health effects is to determine the sources of persistent dampness in the workplace and eliminate them. Also, strict adherence to a housekeeping schedule and use of HEPA-filtered vacuum cleaners will help reduce ambient levels of allergens.

Damp Indoor Environments
Damp indoor environments have been associated with many serious health effects, including asthma, hypersensitivity, and sinusitis. Moisture incursion leading to dampness can result from water leaks and/or by condensation due to high humidity. Common sources of moisture in buildings include: plumbing; roof and window leaks; flooding; condensation on cold surfaces, e.g., pipe sweating; poorly-maintained drain pans; and wet foundations due to landscaping or gutters that direct water into or under the building. Water vapor from unvented or poorly-vented kitchens, showers, combustion appliances, or steam pipes can also create conditions that promote microbial growth.

Steps to Reduce Exposure
Integrated Pest Management Principles should always be implemented. Pesticide products should be used according to application and ventilation instructions provided by the manufacturer. In addition:
- Mix or dilute pesticides outdoors;
- Increase ventilation when using pesticides;
- Use non-chemical methods of pest control when possible;
- Do not store unneeded pesticides;
- Dispose of unwanted containers safely; and
- Keep indoor spaces clean, dry, and well ventilated to avoid pest problems.

Radon
Radon is a colorless, odorless, and tasteless radioactive gas (6, 13, 17, 39, 40). It comes from the natural decay of uranium and some other radionuclides that are present in soil. Radon is responsible for most of the public’s exposure to ionizing radiation (39, 40). It is often the single largest contributor to an individual's background radiation dose, and levels can vary widely from location to location. Radon gas can accumulate in buildings, especially in confined areas such as attics and basements. Radon penetrates cracks and drain openings in foundations, basements, and crawl spaces. Some building materials will also release radon into the air. It can also be found in some spring waters and hot springs, where it can be released into the air when the water is drawn for use indoors. Exposure to radon may cause lung cancer in humans.

The EPA recommends taking actions to reduce radon exposure if levels exceed four picocuries per liter of air (4 pCi/L) (25). Active soil depressurization and building ventilation are the two most commonly used strategies for controlling radon in buildings. Radon reduction methods include sealing concrete slab floors, basement foundations, and water drainage systems, and increasing ventilation.
These techniques are usually cost-effective, and can greatly reduce or eliminate contamination and the associated health risks.

Biological Contaminants
Animals, plants, and microbes are sources of air pollutants. Dander from animals, pollens from plants, and microbes, may act as allergens when they are inhaled. These biological contaminants are usually attached to dust particles of various sizes.

18

Volatile Organic Compounds (VOCs) VOCs refer to organic chemical compounds that have significant vapor pressures, and that can adversely affect the environment and human health. VOCs are emitted as vapors from certain solids or liquids, and include a variety of chemicals, some of which may have short- and long-term adverse health effects (17, 45, 46). Concentrations of many VOCs are consistently higher indoors (up to ten times higher) than outdoors. VOCs are emitted by a wide array of products numbering in the thousands. Examples include paints and lacquers, paint strippers, cleaning supplies, pesticides, building materials and furnishings, office equipment such as copiers and printers, correction fluids and carbonless copy paper, and graphics and craft materials, including glues and adhesives, permanent markers, and photographic solutions (8). More commonly known VOCs include benzene, formaldehyde, methylene chloride, trichloroethylene, and tetrachloroethylene (13). Exposure to VOCs can result in both acute and chronic health effects, depending on many factors such as the level of exposure and the length of exposure. A few VOCs, such as benzene, have been directly linked to cancer in humans, and others are suspected of causing cancer.

Since people today spend most of their time at home or in an office, long-term exposure to VOCs in the indoor environment can contribute to IAQ related problems (31). In offices, VOCs result from new furnishings, wall coverings, and office equipment such as photocopy machines, which can offgas VOCs into the air (47, 48). Good ventilation and air-conditioning systems are essential to reduce VOC emissions in the indoor environment (47).

Steps to Reduce Exposure (http://www.epa.gov/iaq/voc.html)
- Use products according to manufacturer’s directions.
- Make sure that plenty of fresh air is provided when using these products.
- Discard used containers safely.
- Buy quantities that can be used in short periods of time.

Well-designed, -constructed and –maintained building envelopes are critical to the prevention and control of excess moisture and microbial growth by avoiding thermal bridges and preventing intrusion by liquid or vapor-phase water. Management of moisture requires proper control of temperatures and ventilation to avoid high humidity, condensation on surfaces, and excess moisture in materials. Ventilation should be distributed effectively in spaces, and stagnant air zones should be avoided (5, 8).

ASHRAE recommends relative humidity levels between 30 and 60 percent for optimum comfort (25). Higher humidity may result in microbial growth. A consistently implemented good-housekeeping plan is essential to eliminate or reduce the microbial growth in the building.

Legionella
Legionellosis or Legionnaires’ Disease is caused by a waterborne bacterium, Legionella, which grows best in slow-moving, or still warm water (42-44). The primary route of exposure is aerosolization, most commonly from domestic hot-water systems (e.g., showers, sprays, etc.). Mist from evaporative cooling towers without biocide treatment is another reported source. Outbreaks in medical facilities can occur because the patients often have weak or suppressed immune systems.

For cooling towers and evaporative condensers, prevention efforts center on improving the location and maintenance of the cooling towers to limit the growth and spread of Legionella bacteria. These devices should be inspected and thoroughly cleaned at least once a year. Corroded parts, such as drift eliminators, should be replaced, and algae and accumulated scale should be removed. Cooling water should be treated constantly with antimicrobial agents. Ideally, an automatic water-treatment system should be used that continuously controls the quality of the circulating water.

For domestic hot-water systems, prevention efforts focus on controlling water temperature, avoiding dead-legs, avoiding stagnation, and cleaning storage tanks to limit the growth and spread of Legionella bacteria.

INDOOR AIR QUALITY IN COMMERCIAL AND INSTITUTIONAL BUILDINGS | 19

## Appendix B: Steps to Improve Indoor Air Quality³

What employers can do
- Maintain a good working relationship with building management on indoor environmental issues.
- Place office furniture and equipment in locations based on the adequate air circulation, temperature control, and pollutant removal functions of the HVAC system.
- Coordinate with building management when responsibility for design, operation, and maintenance of the ventilation system is shared.
- Avoid procedures and products that can cause IAQ problems.
- Integrate IAQ concerns into purchasing decisions.
- Work with the building manager to ensure use of only necessary and appropriate pest-control practices; use nonchemical methods when possible.
- Work with building management and the contractor before starting to remodel or renovate to identify ways of minimizing building-occupant exposure, and to ensure that the air-distribution system is not disrupted.
- Encourage building management to develop a preventive IAQ management program following guidance issued by the EPA and the National Institute for Occupational Safety and Health.

3See Item 29 in the last section of this document titled “References.”

What workers can do
- Do not block air vents or grilles.
- Water and maintain office plants properly.
- Dispose of garbage promptly and properly.
- Store food properly.
- Avoid bringing products into the building that could release harmful or bothersome odors or contaminants.
- Notify the building or facility manager immediately if you suspect an IAQ problem.

20

Duct and Plenum equipment
n Written inspection and maintenance program.
n Supply, exhaust, return grilles, and ducts clear and clean.
n Routine inspection of ducts, debris, and microbial growth (e.g., semi-annually).
n Provisions of cleanout (e.g., within four feet downstream of duct expansions, supply air openings, or where particulate deposition may occur).
n Ductwork attached, not dented.
n Insulation intact, not wet, and no microbial growth.
n Ductwork properly balanced.

Filtration systems
n Written maintenance, operating, and inspection programs.
n Routine inspection.
n Provision for measuring pressure drops across the filtration system.

## Appendix C: HVAC System Maintenance Checklist⁴

The following checklist can be used to investigate the HVAC system to make sure it is operating properly (e.g., the right mix of fresh air, proper distribution, and filtration systems are working, etc.)

Cooling Towers
n Written maintenance and inspection program. n Operated in accordance with manufacturer specifications.
n Inspected regularly (monthly, or as required). n Treatment of waste to control microorganisms, as required.
n Recordkeeping of biocide use – brand, volume, and results.
n Training of workers for hazards involved.

Humidifiers
n Written maintenance and inspection program. n Inspected weekly during operation.
n Cleaned and disinfected as required.
n No visual buildup of mold or slime.
n Disinfectants removed before reactivating humidifiers.

Cooling Coils
n Written maintenance and inspection program. n Monthly (or, as required) inspections during operation.
n Removal of dirt, slime, and mold, as required. n Upstream filters operating properly.

Drain Pans, drainage systems
n Written maintenance and inspection program. n Monthly inspection (or, as required).
n Drains maintained in free-flowing condition. n No accumulation of stagnant water.
n No buildup of slime, mold, or dirt.
n Removal of dirt, slime, and mold, as required. n Sample water for microbes, as required.

4See Items 24 and 37 in the last section of this document titled “References.”

INDOOR AIR QUALITY IN COMMERCIAL AND INSTITUTIONAL BUILDINGS | 21

## Appendix D: Investigating IAQ Problems and Complaints

Identifying the cause(s) of IAQ problems and complaints may be difficult if an obvious source is not evident. Investigating unclear IAQ problems should take into account patterns and factors, such as occupant complaints and symptoms, location(s) in the building, time of day, seasonal differences, and relationship to activities inside or outside the building. Below are suggestions of information that may be helpful to collect.

Once information is gathered, it should then be analyzed for patterns and possible causes of the IAQ problem. The analysis may point to specific methods, such as those discussed on page 7 (Identification and Assessment). The next step is to fix problems identified and evaluate the results. Has the fix resolved the problems or complaints? If not, then further investigation will need to be pursued. Consultation with safety and health professionals or other experts should be considered at any point during an IAQ investigation.

Information that may be helpful in IAQ investigations:

General office conditions:
- Housekeeping
- How often is the office vacuumed?
- How often are carpet and drapes shampooed?
- How often are floors waxed?
- Are there any visible signs of dust?
- Have pesticides been applied recently?
- Is there any evidence of moisture intrusion into the building?

Air quality in the office:
- Odor
- Dry
- Humid
- Dusty
- Warm
- Cool
- Drafts
- Temperature fluctuation
- Within office
- Between offices
- Between floors
- Any recent changes in:
- Work space
- General office
- Building
- New equipment added to the office

When occupant complaints are related to symptoms or health problems, medical evaluation may be required. Persons with respiratory diagnoses that may be caused or exacerbated by workplace exposures should discuss these with their treating physician, and treating physicians may access additional expertise through the network of National Institute for Occupational Safety and Health (NIOSH)-funded Education and Research Centers, or through the member clinics of the not-for-profit Association of Occupational and Environmental Clinics. Workers’ compensation systems differ by states, but may also be available to support medical care for work-related diseases.

EPA and NIOSH have published two excellent resources to screen and investigate IAQ problems. The first, published in 1991, is Building Air Quality: A Guide for Building Owners and Facility Managers (http://www.cdc.gov/niosh/baqtoc.html). Chapter 6-“Diagnosing IAQ Problems” provides a systematic approach and includes tools, such as logs, questionnaires, diaries, and checklists. The second, published by EPA and NIOSH in 2002, is a companion document that updates and expands on the 1991 publication. The 2002 publication, Indoor Air Quality Education and Assessment Model (I-BEAM) (http://www.epa.gov/iaq/largebldgs/i-beam/index.html),
is separated into modules, and includes online interactive examples of problems and solutions.

22

## Appendix E: Selected Resources

Hazard Recognition
IAQ problems can be caused by improperly operated and maintained HVAC systems, overcrowding, microbiological contamination, outside air pollutants, and off-gassing from materials in the office and mechanical equipment. Related problems also may include discomfort problems due to improper temperature and relative humidity conditions.

The following references aid in recognizing IAQ hazards in the workplace:
- OSHA Technical Manual. OSHA Directive TED 01-00-015 [TED 1-0.15A] (1999, January 20). https://www.osha.gov/dts/osta/otm/otm_toc.html
- Indoor Air Quality Investigation. Contains guidelines for IAQ investigations, recommendations on sampling instrumentation and methods, as well as guidelines for employers to prevent or alleviate IAQ problems. https://www.osha.gov/dts/osta/otm/otm_iii/otm_iii_2.html
- Carbon Monoxide Poisoning. OSHA Fact Sheet (2002) . http://www.osha.gov/OshDoc/data_General_Facts/carbonmonoxide-factsheet.pdf
- Mold. OSHA Safety and Health Topics Page. https://www.osha.gov/SLTC/molds/index.html
- Stachybotrys Chartarum. OSHA Safety and Health Topics Page. https://www.osha.gov/dts/chemicalsampling/data/CH_267785.html#General
- Indoor Environmental Quality. National Institute for Occupational Safety and Health (NIOSH) Safety and Health Topic Page. Links to several other NIOSH publications, including the NIOSH fact sheet on IEQ. http://www.cdc.gov/niosh/topics/indoorenv
- Preventing Carbon Monoxide Poisoning from Small Gasoline-Powered Engines and Tools. U.S. Department of Health and Human Services, National Institute for Occupational Safety and Health Publication No. 96-118, (1996). Gives examples of the many situations in which people have been poisoned because they did not recognize the danger of using small gasoline-powered engines indoors. These poisonings can occur quickly, even in the presence of what many would consider “adequate ventilation,” and in areas that many would define as relatively open spaces, such as parking garages. http://www.cdc.gov/niosh/carbon2.html
- Fact Sheet: Ventilation and Air Quality in Offices. Environmental Protection Agency. Gives an overview of sources of indoor air pollution, health problems and ventilation, control, ventilation standards and building codes, ventilation system problems and solutions, air cleaners, economic considerations, and resolving air-quality problems. http://www.epa.gov/iedweb00/pubs/ventilat.htm
- Air - Indoor Air Quality (IAQ). Environmental Protection Agency. Contains an introduction to IAQ, a listing of common pollutants, and references to IAQ publications, hotlines, and links. http://www.epa.gov/iaq/pubs
- Mold Remediation in Schools and Commercial Buildings. March 2001. Presents guidelines for the investigation, evaluation, and remediation/cleanup of mold and moisture problems in schools and commercial buildings. http://www.epa.gov/iaq/molds/mold_remediation.html
- An Office Building Occupant’s Guide to Indoor Air Quality. Describes factors that contribute to indoor air quality and comfort problems, and the roles of building managers and occupants in maintaining a good indoor environment. http://www.epa.gov/iaq/pubs/occupgd.html
- The Inside Story: A Guide to Indoor Air Quality. Office of Radiation and Indoor Air, U.S. Consumer Product Safety Commission. April 1995. Provides a comprehensive online booklet on IAQ concerns in homes. http://www.epa.gov/iaq/pubs/insidest.html
- IAQ Resources. Provides a listing of various hotlines and resources related to IAQ. http://www.epa.gov/iaq/iaqinfo.html

INDOOR AIR QUALITY IN COMMERCIAL AND INSTITUTIONAL BUILDINGS | 23
- Guidelines on Assessment and Remediation of Fungi in Indoor Environments. New York City Department of Health. Addresses mold contamination of building components (walls, ventilation systems, support beams, etc.) that are chronically moist or water damaged. http://www.nyc.gov/html/doh/html/epi/moldrpt1.shtml
- Indoor Air Quality Publications. Consumer Product Safety Commission (CPSC). Contains an index of CPSC publications related to IAQ. http://www.cpsc.gov/cpscpub/pubs/iaq.html

Evaluation and Control
Methods used in an IAQ investigation may include: identification of pollutant sources; evaluation of HVAC system performance; observation of production processes and work practices; measurement of contamination levels and employee exposure; medical testing or physical examinations; employee interviews; and review of records of medical tests, job histories, and injuries and illnesses.

The following resources provide information about evaluating and controlling IAQ in the workplace.

Evaluation
- Volatile Organic Compounds in Air. OSHA Method PV2120. May 2003. https://www.osha.gov/dts/sltc/methods/partial/pv2120/pv2120.html
- Ozone in Workplace Atmospheres (Impregnated Glass Fiber Filter). OSHA Method ID-214. March 1995. https://www.osha.gov/dts/sltc/methods/inorganic/id214/id214.html
- Carbon Monoxide in Workplace Atmospheres (Direct-Reading Monitor). OSHA Method ID-209. March 1993. https://www.osha.gov/dts/sltc/methods/inorganic/id209/id209.html
- Sulfur Dioxide in Workplace Atmospheres (Impregnated Activated Beaded Carbon). OSHA Method ID-200. April 1992. https://www.osha.gov/dts/sltc/methods/inorganic/id200/id200.html
- Carbon Monoxide in Workplace Atmospheres. OSHA Method ID-210. March 1991. https://www.osha.gov/dts/sltc/methods/inorganic/id210/id210.html
- Formaldehyde in Workplace Atmospheres (3M Model 3721 Monitor). OSHA Method ID-205. December 1990. https://www.osha.gov/dts/sltc/methods/inorganic/id205/id205.html
- Carbon Dioxide in Workplace Atmospheres. OSHA Method ID-179. June 1987. https://www.osha.gov/dts/sltc/methods/inorganic/id172/id172.html
- For additional information, see OSHA's Safety and Health Topics Pages on:
- Formaldehyde https://www.osha.gov/SLTC/formaldehyde/index.html
- Hazardous and Toxic Substances https://www.osha.gov/SLTC/hazardoustoxicsubstances/index.html
- Legionnaires’ Disease https://www.osha.gov/SLTC/legionnairesdisease/index.html
- Sampling and Analysis https://www.osha.gov/SLTC/samplinganalysis/index.html
- Styrene https://www.osha.gov/SLTC/styrene/index.html
- EPA: IAQ Tools for Schools Action Kit. http://www.epa.gov/iaq/schools/actionkit.html
- The National Institute for Occupational Safety and Health (NIOSH), through its Health Hazard Evaluation (HHE) Program, responds to requests from employers, employees and their representatives, and government agencies. NIOSH conducts workplace assessments to determine if workers are exposed to hazardous materials or harmful conditions, and whether these exposures are affecting workers’ health. NIOSH has conducted more than 200 IAQ-related HHEs. Recent reports can be found on NIOSH’s Indoor Environmental Quality website at http://www.cdc.gov/niosh/topics/indoorenv
- Department of Energy. Guide to Operating and Maintaining EnergySmart Schools. Building Technology Program. U.S. Department of Energy. Office of Energy Efficiency and Renewable Energy. http://apps1.eere.energy.gov/buildings/publications/pdfs/energysmartschools/ess_o-and-m-guide.pdf
- GSA 2003 Facilities Standards (P100) Overview. Environmental Policies & Practices. http://www.gsa.gov/portal/content/101230

24

- U.S. Green Building Council LEED for Existing Buildings. Leadership in Environmental and
Energy Design for Existing Buildings. http://www.usgbc.org/DisplayPage.aspx?CMSPageID=221#v2008

Control
- A Brief Guide to Mold in the Workplace. OSHA Safety and Health Information Bulletin. October 10, 2003. https://www.osha.gov/dts/shib/shib101003.html
- Ventilation. OSHA Safety and Health Topics Page. https://www.osha.gov/SLTC/ventilation/index.html
- Building Air Quality: A Guide for Building Owners and Facility Managers. U.S. Department of Health and Human Services, National Institute for Occupational Safety and Health (NIOSH) Publication No. 91-114. Also, referenced as Environmental Protection Agency (EPA) Publication No. 400/1-91/003. December 1991. http://www.cdc.gov/niosh/baqtoc.html
- Building Air Quality: Action Plan. Publication No. 98-123. Also, referenced as EPA Publication No. 402-K-98-001. June 1998. Provides an 8-step building air-quality action plan for building owners and managers to be used with NIOSH Publication No. 91-114 and EPA Publication No. 400/1-91/033. http://www.cdc.gov/niosh/98-123a.html

INDOOR AIR QUALITY IN COMMERCIAL AND INSTITUTIONAL BUILDINGS | 25

## Appendix F: OSHA-Sponsored Environmental Tobacco Smoke Workshops

Workshop I
Workshop Summary: Assessing Exposure to Environmental Tobacco Smoke in the Workplace. Jonathan M. Samet. Environmental Health Perspectives Supplements, vol. 107, no. S2, May 1999.

Environmental tobacco smoke (ETS) is a term now widely used to refer to the mixture of sidestream smoke and exhaled mainstream smoke that pollutes air in locations where tobacco smoking is taking place. A multidisciplinary workshop was convened to address key issues related to ETS exposure in the workplace in order to prepare the groundwork for a risk assessment of the hazard ETS poses to workers. Workshop participants concluded that substantial evidence was now available on worker exposure to ETS using both direct and indirect approaches to exposure assessment, and that these data could be used to project distribution of exposures to ETS in the nation's workplaces. This summary of the discussions at the workshop is an overview of the suggested approach to exposure assessment. http://

ehpnet1.niehs.nih.gov/docs/1999/Suppl-2/309-312samet/abstract.html

Workshop II
OSHA/ACGIH® Environmental Tobacco Smoke Workshop Proceedings, Publication #99-078

Proceedings of the OSHA/ACGIH® Environmental Tobacco Smoke Workshop held June 6, 1998, in Cincinnati, OH. The workshop brought together a panel of ventilation experts, along with hospitality industry managers and design engineers, to discuss effective and non-effective ventilation strategies for smoking sections in restaurants and bars.

Workshop III
Workshop Summary: Workshop on Health Risks Attributable to ETS Exposure in the Workplace. Maritta S. Jaakkola and Jonathan M. Samet (Johns Hopkins University, Baltimore, Maryland, USA). Environmental Health Perspectives, vol. 107, supp. 6, December 1999.

This 1998 workshop was convened to address the health risks of exposure to environmental tobacco smoke (ETS) in the workplace. It was paired with a 1997 workshop on issues related to ETS exposure in work environments. The 1998 workshop involved a multidisciplinary group of participants who reviewed evidence on the quantitative risks to health posed by ETS and discussed the development of risk assessment methodology for the future.

26

## References

1. U.S. EPA. An Office Building Occupant's Guide to Indoor Air Quality. http://www.epa.gov/iaq/pubs/occupgd.html
2. U.S. EPA. Indoor Air Quality. The Inside Story: A Guide to Indoor Air Quality. http://www.epa.gov/iaq/pubs/insidest.html
3. CDC. Healthy Housing Reference Manual. Chapter 5: Indoor Air Pollutants and Toxic Materials. http://www.cdc.gov/nceh/publications/books/housing/cha05.html
4. NIOSH Recommendations for the Cleaning and Remediation of Flood-Contaminated HVAC Systems: A Guide for Building Owners and Managers. http://www.cdc.gov/niosh/topics/emres/Cleaning-Flood-HVAC.html
5. American Society of Heating, Refrigerating and Air-Conditioning Engineers (ASHRAE) (2010). ASHRAE Standard 62.1. Ventilation for Acceptable Indoor Air Quality. Atlanta, GA.
6. Fisk, W.J. (2000). Health and Productivity Gains from Better Indoor Air Environments and Their Relationship with Building Energy Efficiency. Annual Review of Energy and the Environment, 25: 537-566.
7. Spengler, J. D., Samet, J. M., and McCarthy, J. F. (2001). Indoor Air Quality Handbook. McGraw-Hill.
8. U.S. EPA. An Introduction to Indoor Air Quality (IAQ). http://www.epa.gov/iaq/ia-intro.html#Indoor%20Air%20Pollution%20and%20Health
9. American Thoracic Society. Environmental Controls and Lung Disease. American Review of Respiratory Disease, 1990, 142: 915-939.
10. American Lung Association. Health Effects and Sources of Indoor Air Pollution, Parts I and II, 1989, Publication No. 0857C. http://www.indoorpollution.com/air_pollution.htm
11. European Concerted Action. Indoor Air Quality & Its Impact on Man. Environment and Quality of Life. Report 10. Effects of Indoor Air Pollution on Human Health (1991).
12. U.S. EPA. Indoor Air Pollution: An Introduction for Health Professionals. (Last updated April 28, 2010). http://www.epa.gov/iaq/pubs/hpguide.html
13. Bernstein, J. A., Alexis, N., Bacchus, H., Bernstein, I. L., Fritiz, P., et al. (2008). The Health Effects of Nonindustrial Indoor Air Pollution. Journal of Allergy and Immunology, 12(3): 585-590.
14. Stapczynski, J.S., 2004. Chapter 62: Respiratory Distress. Tintinalli, J.E., Kelen, G.D., Stapczynski, J.S., Ma, O.J., and Cline, D.M. Tintinalli’s Emergency Medicine, 6th Edition.
15. World Health Organization (WHO) (2009). WHO Guidelines for Indoor Air Quality: Dampness and Mould. http://www.euro.who.int/__data/assets/pdf_file/0017/43325/E92645.pdf
16. CDC Online Source for Credible Health Information: Mold. http://www.cdc.gov/mold
17. OSHA. Preventing Mold-Related Problems in the Indoor Workplace. OSHA 3304-04N 2006. http://www.osha.gov/Publications/preventing_mold.pdf
18. CDC. Healthy Housing Reference Manual. Chapter 5, Indoor Air Pollutants and Toxic Materials. http://www.cdc.gov/nceh/publications/books/housing/cha05.html
19. U.S. EPA. IAQ Building Education and Assessment Model (I-BEAM): TIA Maintenance and Housekeeping Programs.
http://www.epa.gov/iaq/largebldgs/i-beam/text/maintenance_and_housekeeping.html#IAQ%20Housekeeping%20 Tasks
20. OSHA. A Brief Guide to Mold in the Workplace. OSHA Safety and Health Information Bulletin, October 10, 2003. http://www.osha.gov/dts/shib/shib101003.html
21. Institute of Medicine (IOM) (2004). Damp Indoor Spaces and Health. Washington, DC: National Academy of Sciences.
22. Fisk, W. J., Lei-Gomez, Q., Mendell, M. J. (2007). Meta-analysis of the Associations of Respiratory Health Effects with Dampness and Mold in Homes. Indoor Air 17(4):284-296.
23. World Health Organization (WHO) (2009). WHO Guidelines for Indoor Air Quality: Dampness and Mould. WHO Regional Office for Europe. http://www.euro.who.int/__data/assets/pdf_file/0017/43325/E92645.pdf

INDOOR AIR QUALITY IN COMMERCIAL AND INSTITUTIONAL BUILDINGS | 27
24. U.S. EPA. Indoor Air Quality. Tools for Schools Action Kit IAQ Coordinator’s Guide: A Guide to Implementing an IAQ Program. http://www.epa.gov/iaq/schools/tools4s2.html
25. ASHRAE Standard 55 (2010). Thermal Environmental Conditions for Human Occupancy.
26. ASTM Standard D-6245-98. Using Indoor Carbon Dioxide Concentrations to Evaluate Indoor Air Quality and Ventilation.
27. U.S. Consumer Product Safety Commission. Tips for Purchasing and Installing New Carpet. CPSC Document #454. http://www.cpsc.gov/cpscpub/pubs/454.html
28. Carpet and Rug Institute (1999). Carpet and Indoor Air Quality Technical Bulletin. http://www.carpet-rug.org/technical_bulletins/9902_Carpet_and_IAQ.pdf
29. NIOSH. Building Air Quality: Action Plan. http://www.cdc.gov/niosh/baqact4.html
30. U.S. Consumer Product Safety Commission. The Senseless Killer. 1993 GAO Publication
No. 1993-0-356-764.
31. Mott, J. A., Wolfe, M. I., Alverson, C. J., Macdonald, S. C., Baily, C. R., Ball, L. B., et al. (2002). National Vehicle Emissions Policies and Practices and Declining U.S. Carbon Monoxide Mortality. JAMA, 288: 988-995.
32. American Lung Association. Carbon Monoxide Indoors. http://www.lungusa.org/healthy-air/home/resources/carbon-monoxide-indoors.html
33. U.S. EPA. An Introduction to Indoor Air Quality: Carbon Monoxide. http://www.epa.gov/iaq/co.html
34. OSHA. Carbon Monoxide Poisoning. Fact Sheet, 2002. 2 pages. http://www.osha.gov/OshDoc/data_General_Facts/carbonmonoxide-factsheet.pdf
35. OSHA. Carbon Monoxide in Workplace Atmospheres. OSHA Method ID-210, March 1991. http://www.osha.gov/dts/sltc/methods/inorganic/id210/id210.html
36. Health Canada. Indoor Air Quality in Office Buildings. Carbon Dioxide. http://www.hc-sc.gc.ca/ewh-semt/pubs/air/office_building-immeubles_bureaux/co2-eng.php
37. Canadian Centre for Occupational Health and Safety. Health Effects of Carbon Dioxide Gas. http://www.ccohs.ca/oshanswers/chemicals/chem_profiles/carbon_dioxide/health_cd.html
38. U.S. EPA. An Introduction to Indoor Air Quality: Pesticide. http://www.epa.gov/iaq/pesticid.html
39. U.S. EPA. A Citizen’s Guide to Radon. The Guide to Protecting Yourself and Your Family from Radon. EPA 402/K-09/001. January 2009. http://www.epa.gov/radon
40. Agency for Toxic Substances and Disease Registry (ATSDR). Radon. September 2008.
CAS ID #: 14859-67-7. http://www.atsdr.cdc.gov/substances/toxsubstance.asp?toxid=71
41. OSHA. Mold. Safety and Health Topics Page. http://www.osha.gov/SLTC/molds/index.html
42. Canadian Centre for Occupational Health and Safety. Legionnaires Disease. http://www.ccohs.ca/oshanswers/diseases/legion.html
43. CDC. Legionellosis Resource Site (Legionnaires’ Disease and Pontiac Fever). Patient Facts: Learn More about Legionnaires’ disease. http://www.cdc.gov/Legionella/patient_facts.html
44. OSHA. Legionnaires’ Disease. Safety and Health Topics Page. http://www.osha.gov/SLTC/legionnairesdisease/index.html
45. OSHA. Volatile Organic Compounds in Air. OSHA Method PV2120, May 2003. http://www.osha.gov/dts/sltc/methods/partial/pv2120/pv2120.html
46. U.S. EPA. An Introduction to Indoor Air Quality: Volatile Organic Compounds (VOCs). http://www.epa.gov/iaq/voc.html
47. Yu, C. and Crump, D. (1998). A Review of Emission of VOCs from Polymeric Materials Used in Buildings. Building and Environment, 33(6): 357-374.
48. Hrigaray, P., Newby, J. A., Clapp, R., Hardell, L., Howard, V., et al. (2007). Lifestyle-Related Factors and Environmental Agents Causing Cancer. An Overview. Biomedicine and Pharmacotherapy, 61(10): 640-658.

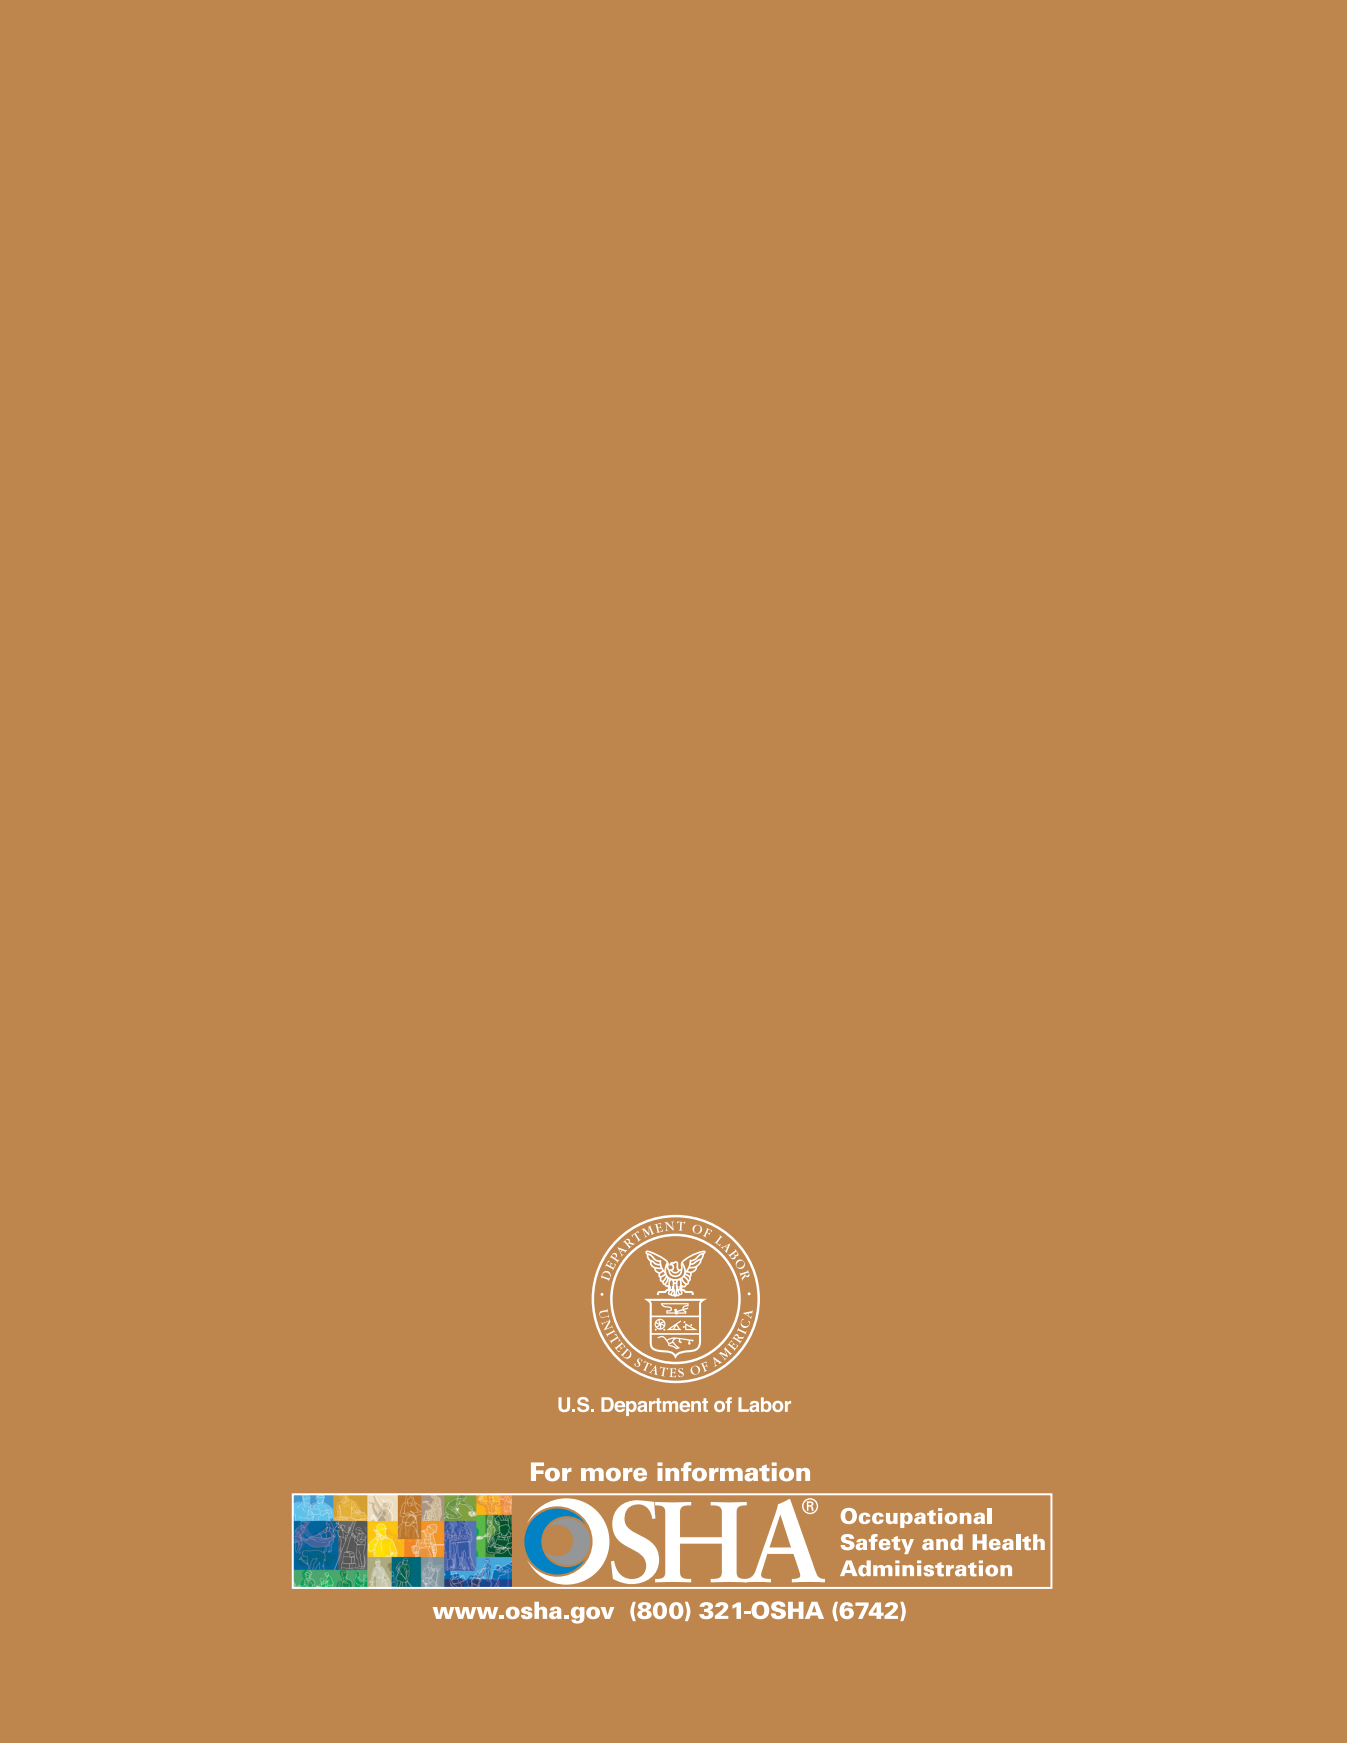
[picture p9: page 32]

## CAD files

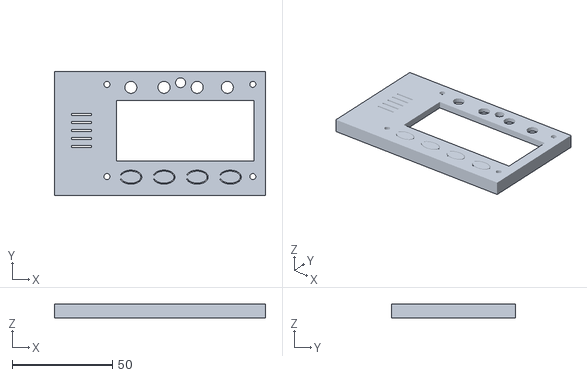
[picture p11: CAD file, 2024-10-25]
supporting material/case/Case_Top_20220220_2.stl
105.0 x 61.5 x 7.00

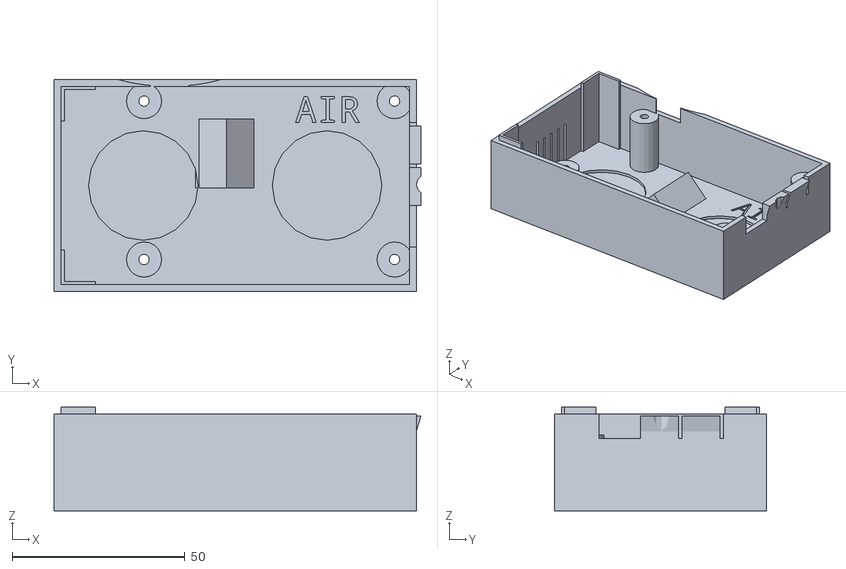
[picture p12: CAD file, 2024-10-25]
supporting material/case/Case_Bottom_20220220.stl
106.3 x 61.5 x 30.0

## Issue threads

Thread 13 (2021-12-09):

zuluDateTimeString should use timeStatus()

ericklein, 2021-12-09:
in zuluDateTimeString switch the #ifdef NTP to instead check timeStatus() for timeNotSet

ericklein, 2022-02-10:
fixed in refactor branch. Awaiting testing.

Closed 2022-02-10.

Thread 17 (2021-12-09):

Unified message manager

ericklein, 2021-12-09:
Add a unified message manager that handles debug, alert, and fatal messages across serial monitor, LED, screen, and (mqtt) logging.

ericklein, 2022-01-02:
debug, error, fatal across serial, LED, screen, and backend

ericklein, 2022-02-10:
It's hard to handle error display via LED, screen, and server (mqtt) logging when you don't if the output location is even there (yet, depending on when in code you need to output an error message) or will be there for long (one time code run followed by sleep/reset.

Closed 2022-02-10.

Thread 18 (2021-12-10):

deepSleep for ARM implementations

ericklein, 2021-12-10:
implement deepsleep() for ONETIME implementations using an ARM MCU

ericklein, 2022-02-10:
Required for #define RJ45 to work in the refactor code branch, which will be promoted to master when stable for #define WiFi

ericklein, 2022-06-09:
Closing this issue. All future hardware work is expected to remain on ESP32 MCU

Closed 2022-06-09.

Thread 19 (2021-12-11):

SCD40 temperature calibration

ericklein, 2021-12-11:
SCD40 is samping ~ 4F higher than external sensor sitting next to it. Need to check with calibrated sensor to determine which sensor is inaccurate, and if SCD40, look for calibration API

ericklein, 2022-06-10:
Look at setSensorAltitude() and/or setAmbientPressure()

ericklein, 2022-06-10:
implemented setSensorAltitude() and it is in testing

ericklein, 2022-06-12:
scd40 branch implemented setSensorAltitude() and a power management change, but I'm not sure the current code has any other calibration issues that can be addressed in software. There is a recommended way to initially calibrate the sensor which involves a week of indoor and outdoor (lowest CO2 level) time. We could also look at case design, but I don't think there is a significant issue?

Closed 2022-06-12.

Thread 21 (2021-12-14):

batteries running down much faster than expected

ericklein, 2021-12-14:
days instead of weeks. Correlated in time frame to integration of new code and SCD40

ericklein, 2022-01-02:
Changing bug to P2 so it will be addressed after the code refactoring

ericklein, 2022-01-02:
need to monitor power use via external tool

ericklein, 2022-01-03:
SCD40 was pushing data every 5 seconds causing a consistent power draw during deep sleep. Issue resolved via implementing stopPeriodicMeasurement() in deepSleep() routine.

Closed 2022-01-03.

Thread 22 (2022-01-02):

Battery monitor not detected is a FATAL error

ericklein, 2022-01-02:
If the LC709203 is not detected, the client code will not run. This should not be FATAL because if the battery runs down but we can't detect it, the backend will not receive sensor values over an extended window causing a different backend error which will alert owner to the underlying issue.

ericklein, 2022-02-10:
fixed in the refactor branch. Needs to be tested.

Closed 2022-02-10.

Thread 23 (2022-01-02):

Battery monitor visualization is incorrect

ericklein, 2022-01-02:
Battery levels displayed on screen are incorrect, appearing lower than they actually are. 18% is being visualized as ~ 10% in the graphic.

ericklein, 2022-06-12:
I'll fix this when I do the UI refresh

ericklein, 2023-01-08:
Units are also not showing 100% charge when fully charged. Fully charged is battery dependent, so maybe we loosen our battery display algorthym requirements to larger (%) visual "chunks" that give the user an approximate range the battery is in?

ericklein, 2023-07-05:
Assuming the LC709203F percent value is accurate, you could use its values to validate key value (<10%, 100%, 50%?) visualization. It's a known bug that the software calculation is a straight line degradation and therefore not accurate (independent of visualization) once you get close to 3.6v, where voltage drops precipitously to 3.2v.

ericklein, 2023-07-05:
I've reviewed this issue using an upgraded battery_check app with the battery gauge code from RCO2/AQ. The gauge is accurate. The code for software approximation of battery percentage is incorrect and will be fixed via a custom LUT vs linear approximation.

ericklein, 2023-07-22:
The formula for determining the width of the displayed battery level based on battery percentage is incorrect. Any battery percentage below ~18% in the current calculation will display as an empty (no pixel width) battery. A more correct pseudo-formula is int(0.5+((battery_percentage*(barWidth-4)/100)). The roundup for the int calculation introduces some error rate in overestimating remaining battery, but the # of pixels used to represent the value is so low it is "good enough".

ericklein, 2023-07-22:
implemented in rco2. These two changes need to be tested.

ericklein, 2023-07-22:
implemented in aq for testing. AQ does not have software approximation changes yet as deployed hardware uses LC709203F.

Closed 2023-11-04.

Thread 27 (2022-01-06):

filter OWM JSON results before handling

ericklein, 2022-01-06:
use the arduinojson library filtering functions to reduce memory requirements by filtering what JSON data is desired from larger object.

ericklein, 2023-03-23:
Memory usage to get the OWM json results is isolated to a function. That function has unused fields commented out, along with the corresponding elements in the global data struct. A arduinojson filter call would lower temporary memory usage somewhat, but is not needed on ESP32 at this time.

Closed 2023-03-23.

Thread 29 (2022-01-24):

sensor data not displayed if network connection doesn't happen

ericklein, 2022-01-24:
refactor the code to allow local read and display to occur even if the network connection is not possible

ericklein, 2022-02-10:
refactor branch fixes this issue. Needs to be tested.

Closed 2022-02-11.

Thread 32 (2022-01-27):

PM 2.5 sensor integration

ericklein, 2022-01-27:
Integrate PM 2.5 sensor data

disquisitioner, 2022-03-14:
Will be good to sync on the preferred approach here.  The most direct way would be to connect a PM2.5 sensor via I2C and read data from it alongside the CO2 sensor.  This should be easy electrically (and in software) but introduces a potentially significant power drain due to the airflow fan in the sensor plus the need to run the sensor for a short period to start getting reliable readings.   Also would need a larger case with more airflow, but that might allow a larger battery and mitigate some of the power concerns.  But all doable.

An alternative would be to design PM2.5 measurement as a companion device that is optimized for handling typical PM2.5 sensors and perhaps would be in a different location.  The sensor and reporting code could largely be the same as the directly-integrated case.

Having a stand-alone PM2.5 unit at least for development and testing would all exploring power consumption and sampling cycle constraints, so will start there while we talk through the overall design approach.

disquisitioner, 2022-06-04:
As an update, I have a separate code base using an Sensirion [SEN54 particulate sensor](https://www.sparkfun.com/products/19325) with I2C intervace, running on an Adafruit Feather, uploading data both to Dweet.io and my InfluxDB backend.  As a starting point I'll create a public repo with that code so we can take a look and see how to align the implementation there with infrastructure we've already worked out here for air_quality.

disquisitioner, 2022-06-05:
My current PM2.5 AQI sensor project code is now on github at [https://github.com/disquisitioner/Feather-AQI-Monitor-SEN54](https://github.com/disquisitioner/Feather-AQI-Monitor-SEN54).   Issues, new feature ideas, and pull requests are welcome!

Closed 2022-06-09.

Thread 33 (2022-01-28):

remove Serial.println

ericklein, 2022-01-28:
transition all Serial.println to debugMessage()

ericklein, 2022-02-10:
all Serial.println replaced with debugMessage in refactor branch. Validate in testing then remove commented Serial.print statements.

Closed 2022-02-10.

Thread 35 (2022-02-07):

Local trend on display

VaderPanda, 2022-02-07:
Display trend information on display in 12hrs, 24hrs, and 72hrs modes.  For the purpose of prototyping, we could use these symbols to represent the data:
"/" trend up - data is trending up compared to the previous time segment
"\" trend down - data is trending down compared to the previous time segment
"-" trend even - data is even compared to the previous time segment.

12 segment is all we need at this time.  In 12hrs mode, each segment represents average sample data for one hour.  In 24hrs mode, each segment represents average sample data for two hours.   In 72hrs mode, each segment represents average sample data for six hours.

If we stay with the current three lines format on the display.  Using the left side of the display.  The top line would be 12hrs mode, the mid line would be 24hrs mode, the bottom line would be 72hr mode.

Delta triggers from [https://github.com/ericklein/air_quality/issues/7]
Temp changes by 1 degree F
Humidity changes by 1%
CO2 level changes by 25

disquisitioner, 2022-02-07:
I was looking at adding sample averaging to the code already, which might dovetail nicely here.  We currently take one sensor reading per reporting interval, which by default is every 30 minutes.  We could read the sensors more often and average them, even though we might still only report results on the display and to the cloud every 30 minutes.  We'd need to wake up the device more often to do that, which would consume more power, but we'd only need to wake up and power the sensor section at each sampling, not the wifi (or display, MQTT back-end, etc.).

ericklein, 2022-02-07:
Related to #7

ericklein, 2023-02-27:
See #72

Closed 2023-02-27.

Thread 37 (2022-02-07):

Add support for dweet.io

disquisitioner, 2022-02-07:
Add support for [dweet.io](https://dweet.io), which provides a free cloud service for devices to publish messages and information,  This would make it easy to see the most recent sensor readings, information about the device itself (e.g., WiFi RSSI and IP address) and even error/status messages.    Uploads happen via an HTTP POST and JSON, which is easy to add given we already have HTTP connectivity support in the app.

ericklein, 2022-03-14:
completed and in master

Closed 2022-03-14.

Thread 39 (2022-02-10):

Parse timezone from OWM data

ericklein, 2022-02-10:
Could one use the timezone from OWM data to automatically set the time zone in the NTP set function?

ericklein, 2022-02-10:
would require re-arranging functions in setup(), e.g. one time run.

ericklein, 2022-03-14:
will not fix, OWM data is not real time accurate

ericklein, 2022-05-12:
since logging destination is timestamping independently, using OWM time on screen, even if off by ~ 1 minute, would not impact anything. As long as the AQ device isn't also being used as a clock :)

ericklein, 2022-06-12:
Bumping priority to address before Fall. I'll work on this when I open up more of the OWM data for the new UI.

ericklein, 2022-10-30:
Using OWM Current Weather API timezone field to get local UTC offset. If that is not available, use the backup time zone set in config.h.

I modified aq_network.cpp and aq_network.h to not automatically set UTC time when initializing a network connection, instead adding a new setTime function that allows the UTC offset to be passed in. We don't know the UTC offset until we call the OWM Current Weather API. One we have that, or not, we can set the time.

Closed 2022-10-30.

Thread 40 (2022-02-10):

error handling for screen not attached

ericklein, 2022-02-10:
Need to look at error handling for display.begin()

ericklein, 2022-05-01:
I added a conditional handler for display.begin(), but the routine doesn't return anything. I've checked a few Arduino EPD libraries, and none seem to check if the screen is responding properly. I've logged an issue against the library and asked in the forums how to handle this.

ericklein, 2022-05-12:
EPD is write only so @ladyada closed my issue as un-fixable.

Closed 2022-05-12.

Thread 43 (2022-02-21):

Data should be floating point internally, and converted to integers as appropriate for display and export

disquisitioner, 2022-02-21:
Currently sensor readings are converted to integers as part of acquiring values from the sensors (both attached sensors and through getWeather().  That's probably fine for what's shown on the display, but causes loss of precision given most of our sensors are more accurate than that, the data is now also being shared with other services (e.g., MQTT and Dweet), and we've also talked about adding database support to store values for subsequent analysis, alert triggers, IFTTT, etc.

I propose we store data internally as floating point wherever relevant and convert it to integer or fixed point wherever necessary -- in the code that displays values on the eInk display, before they get sent to other services, etc.

This would require changing the envData typedef/struct to use floats rather than uint16_t, at least for temperature and humidity values.  (Our current CO2 sensor returns readings as an integer, so CO2 values could stay uint16_t.)  There would be minimal change in readSensor() and getWeather() as in most cases conversion from the floating point sensor values to integers happens implicitly via the compiler through assignment.  (The exception here is temperature, which gets converted from C to F and then cast as an integer.)  Some change would also be needed to infoScreen() to properly format floats as integers (or fixed precision) for display.

I like the idea that we'd retain whatever values sensors provide as our internal data model and let any code using that data for display, sharing, export, storage, alerts, etc. do the right math at the point of use, whatever that may turn out to be (and which they know best anyhow).

ericklein, 2022-03-22:
I've implemented this change in nvstorage branch and will promote after testing is complete. The new core data struct is:

typedef struct
{
  float internalTemp;
  float internalHumidity;
  uint16_t internalCO2;
  int extTemperature;
  int extHumidity;
  int extAQI;
} envData;

To handle data persistence, extra variables I create mimic the core struct's data types.

Closed 2022-03-22.

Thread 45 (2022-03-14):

post_dweet() Ethernet support

ericklein, 2022-03-14:
post_dweet() has WiFi connection check but not for Ethernet. It might be better to say we need a generic handler to check Internet status?

disquisitioner, 2022-03-15:
Good point.  We have two physical device configurations via #define for WiFi and wired, and then one global state variable that says whether there's an active connection or not that gets used in an if test inside that compiled code.   I'll take a look at ways to make that more straightforward given there are few generalizable functions that could be called independent of WiFi vs. wired.

ericklein, 2022-05-01:
Closing this is dependent on headless execution, which is currently not working. I'll work on the headless issue as a branch from master.

disquisitioner, 2022-05-12:
I think this should work now given the introduction of a generalized networking interface that handles WiFi and Ethernet connectivity identically.   Will be good to test to make sure that's the case, though.

disquisitioner, 2022-06-04:
The recent generalization of the networking code (via aq_network.cpp) enabled post_dweet() and post_influx() operations with Ethernet as well as on WiFi.  This bug is therefore fixed, though it would be good to test it with working Ethernet hardware (hard wired, not WiFi).

Closed 2023-02-27.

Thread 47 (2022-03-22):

DWEET support for when CO2 sensor is not available

ericklein, 2022-03-22:
When CO2 sensor is not available, AQ uses the convention of setting sensorData.internalCO2 to 10000. DWEET will attempt to push CO2 values even when there is no sensor reading it, so it will push 10000 upstream. Is that the intended behavior?

disquisitioner, 2022-03-23:
Good catch!   I see from looking at readSensor() that it sets internal CO2, temperature and humidity to 10000 if no data was read from the sensor.  I hadn't spotted that before.  Knowing that indicates an error condition I will add a test so post_dweet() doesn't get called if that error (no data) exists.  Thanks.

disquisitioner, 2022-03-23:
I added the required if() test in the network update branch I'm working on, so will follow up here when that pull request goes in.  (I added that same logic to apply to uploading data to InfluxDB.)

ericklein, 2022-05-12:
I modified the logic due to another bug for DWEET, MQTT, and Influxdb, and verified in MQTT and Influxdb that values publish when CO2 = 10000 (no CO2 sensor) and when we have an actual value. I'm going to close this bug. @disquisitioner you can reopen if there is an issue.

Closed 2022-05-12.

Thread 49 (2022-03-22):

Add a routine to clear nv storage

ericklein, 2022-03-22:
Need a routine to clear nv storage in the case of the value pool being incorrect and there is a need for accurate data to be uploaded. If given enough time, the averages will clean themselves of errant values, but if time to report accurate values is critical, we could add a routine to remove all values and let the code restart building the averages.

ericklein, 2022-06-09:
nvstorage is now (re)initialized after every sample set is completed.

Closed 2022-06-09.

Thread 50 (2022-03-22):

internalTemp is never set to 10000 although code has checks for it

ericklein, 2022-03-22:
Routines looking for a missing temp/humidity sensor look for sensorData.internalTemp == 10000, though there is no place in the code that sets this. The code moved to deepSleep() when a sensor is not available (see if the problem goes away on its own) so these ==10000 dependencies need to be addressed.

ericklein, 2022-06-09:
issue does not exist in current code base

Closed 2022-06-09.

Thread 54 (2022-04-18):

SAMPLE_SIZE 1 breaks averaging logic

ericklein, 2022-04-18:
Sample size = 1 breaks the averaging logic because /SAMPLE_SIZE is dividing by 1.

ericklein, 2022-05-12:
SAMPLE_SIZE logic is also effective one less than expected, e.g., SAMPLE_SIZE 2 triggers on first run, as the logic resets it to 1 on publish, not 0.

disquisitioner, 2022-06-02:
Setting SAMPLE_SIZE to 1 (e.g., in config.h) breaks the averaging logic for a couple of reasons, but then the averaging logic is currently broken for a different reason.  If left running over an extended period of time the environmental values reported e.g. via Dweet or InfluxDB will gradually drift higher and higher due to a bug that relates to how the averaging logic currently works.  (This is because all the external reporting functions use the average values computed, not the current sensor readings.)  Recently my Air Quality unit has been reporting temperatures in my dining room in excess of 104F and rising, which is clearly wrong.  This error will also make the delta value shown on the display get higher and higher without end, though the current readings shown on the display are correct.

More specifically:
a) The averaging logic uses a sampleCounter variable that is stored in and read from NV memory
b) The averaging logic retains the most recently computed average and includes it as a data point in computing the next average.  In every averaging cycle that previous rolling average is therefore always data point #1 (out of SAMPLE_SIZE total data points).
c) The averaging logic divides by SAMPLE_SIZE, not sampleCounter, though sampleCounter is compared to SAMPLE_SIZE to determine when to do the averaging and report those averaged values.  This is OK, but dangerous.
d) To do the averaging correctly you need to divide by the actual number of measurements, including some number of sensor readings plus the most recently reported average value (stored in and retrieved from NV memory).  This means sampleCounter needs to start at 1 since is is pre-incremented (and then stored) as part of the averaging process.
e) Lastly, and this is the bug that causes the averaged value to increase monotonically over time and therefore eventually give erroneously high readings), when the sampleCounter variable is reset after a completed averaging cycle the code at line #174 in air_quality.cpp resets it to 0 when it should reset it to 1.  (Note that sampleCounter is initialized to 1 in line #569 of air_quality.cpp if it is otherwise not present in NV memory, which is correct.)

Having the sampleCounter reset to 0 after an averaging cycle results in the average being computed incorrectly as it adds the most recently reported average together with SAMPLE_SIZE sensor readings, giving a total of (SAMPLE_SIZE +1) measures, but then that aggregate total is divided by SAMPLE_SIZE.  Changing line #174 in air_quality.ino so it initializes sampleCounter to 1 fixes this problem as it results in ((averageTemp + (SAMPLE_SIZE -1) sensor readings) /  SAMPLE_SIZE) and causes the unit to begin reporting accurate average values (for all sensors, I might add) via Dweet, InfluxDB, and MQTT.

Alternatively, you could have sampleCounter reset to 0 at the beginning of each cycle (and be initialized to 0 in line #569) but would need to change how sampleCounter and SAMPLE_SIZE are used and compared in implementing the averaging cycle.  Given the way the code actually works at present, sampleCounter needs to be initialized to 1, not 0.

It would also be possible to modify the code so setting SAMPLE_SIZE to 1 worked properly by altering the if() logic that tests for when to do the averaging calculation.  Having an averaging that's only of 1 sample isn't really averaging, though, so perhaps isn't appealing as a feature of the air_quality software.

ericklein, 2022-06-03:
I'll work through your comments and I've already revised much of this code in my ui+avg-logic branch, which I've had in testing for some time. Didn't want to integrate into master until I knew it was solid.

ericklein, 2022-06-09:
Fixed verified in store_rssi branch from master during testing.

Closed 2022-06-09.

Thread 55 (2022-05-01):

co2 not publishing to MQTT

ericklein, 2022-05-01:
version : influx_v1_v2 that will be promoted to master.
reproduced on two separate installs.

this could be an issue given I've been editing the sensor code in this branch and perhaps I introduced the problem, or it is inherent in this branch. Let's evaluate once we've integrated into master

ericklein, 2022-05-12:
this was a logic problem that affected all internet publishing routines. If CO2 was 10000, the problematic logic would not publish anything. This was fixed and pushed to master.

Closed 2022-05-12.

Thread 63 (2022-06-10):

Temp, humidity delta is reporting <1 changes as 1 in infoScreen

ericklein, 2022-06-10:
sensor value = 66.32
averaged value (from total sample set) is 66.52

This is an edge case where subtracting the rounded (+.5) (int) of these values yields -1 even though the temperature did not change 1 degree.

Solution is likely to (int) the base values and look for >1 movement.

ericklein, 2022-06-12:
will fix during the UI refresh

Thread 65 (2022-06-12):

Screen not updating for many hours at a time

ericklein, 2022-06-12:
Some devices are not updating their screens and data sources for hours or days at a time, but I do not understand why. The devices have sufficient battery charge. If they can not connect to the Internet, they are supposed to update the screen only and display an error message about the lack of connectivity. This is not happening.

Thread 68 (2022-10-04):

Text wrapping for screen display

ericklein, 2022-10-04:
screenAlert can accept messages with lengths longer than available space. will need a better wrapping function than provided by .print.

ericklein, 2023-11-14:
Across all projects, implemented setTextWrap(false) to stop wrapped text from overwriting other UI elements. screenAlert now centers text on both x and y axis and throws an ERROR debug message if the message is too long. It will still display the message text, just truncated at x=0 and x=display.width(). This allows some error messaging to be displayed, and the user will immediately notice the UI problem and can also alert a developer who missed it visually or in DEBUG.

Closed 2023-11-14.

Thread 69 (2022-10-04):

Battery monitoring for non-LC709203

ericklein, 2022-10-04:
Most of the Adafruit ESP32 Feather boards have a technique for monitoring at least battery voltage. Can I create a LUT to determine battery percentage or use the LUT the LC709203 library uses? I think @disquisitioner has explored this idea?

ericklein, 2022-10-28:
Implemented for ESP32 V2, which has the necessary hardware. Other boards implementing this voltage monitoring technique can be added.

Closed 2022-10-28.

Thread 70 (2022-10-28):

Handle error condition for RJ45 and retrieving RSSI value

ericklein, 2022-10-28:
This error condition is not currently handled in the code.

ericklein, 2023-03-23:
Recent changes removed global to store network connectivity status, so when/if we rebuild the RJ45 branch, this has to be addressed.

Closed 2024-11-25.

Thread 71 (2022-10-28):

Battery display shows board default voltage when no battery attached and USB power

ericklein, 2022-10-28:
Example: Adafruit Feather ESP32S2 board voltage is ~ 3.7v. LC709203F returns 3.71V when no battery is attached but USB power is attached. This leads to an incorrect battery display of ~14% battery life.

ericklein, 2023-02-27:
need to work on detecting "ac" state and displaying a different UI element

ericklein, 2023-07-05:
LC709203F doesn't work properly when the battery is not attached, per specification

ericklein, 2023-07-05:
closing issue

Closed 2023-07-05.

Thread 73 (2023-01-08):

5x sample CO2

ericklein, 2023-01-08:
Researching best practices to get an accurate sample from the SCD40, it appears that reading the sensor multiple times and taking the last sample as actual allows the sensor to calibrate properly, versus a single read from a "cold" sensor.

ericklein, 2023-01-17:
added a config.h define to control the number of times the SCD40 is read before environment data is stored

Closed 2023-01-17.

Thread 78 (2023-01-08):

low power warning during initialization phase

ericklein, 2023-01-08:
Move power management routines earlier in the task cycle and determine if there is enough power for the cycle to proceed. Current firmware often reports a SCD40 not found error when there is not enough battery voltage to properly bring up the SCD40.

ericklein, 2023-11-04:
This change has been implemented for some time.

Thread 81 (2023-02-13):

Change WiFi reconnect time to <10 seconds

ericklein, 2023-02-13:
WiFi error logs suggest that either we can't reach the desired AP at all, or the connect/disconnect error happens quickly. There is a common error case where the AP asks the device to reconnect in 1024ms.

This suggests that waiting 10 seconds between WiFi connect attempts does not increase the likelihood of a successful subsequent connection. Let's change it to 5 seconds and test. This will have the secondary benefit of ever so slightly reducing battery consumption.

ericklein, 2023-02-18:
changed to 5

Closed 2023-02-18.

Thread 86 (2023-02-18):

Move AQI rating from European to US standard

ericklein, 2023-02-18:
OWM AQI value returned is a European-standards value as opposed to the US standards body computed value. Please translate the raw OWM PM2.5 value to the US AQI value and display that instead. This ensures a standard returned value between the AQ and PM25 projects and devices if viewed side by side.

ericklein, 2023-02-24:
Code fix implemented in feb-ui branch, verification required.

ericklein, 2023-02-27:
code is working, there is a display issue with long US names that needs to be resolved before closing this.

ericklein, 2024-11-25:
this system has been replaced with a unified AQI labeling scheme and will be promoted to /main shortly.

Closed 2024-11-25.

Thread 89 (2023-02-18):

Replace batteryVoltageAvailable with actual value test

ericklein, 2023-02-18:
Code currently stores a valid voltage reading if available and a global flag (batteryVoltageAvailable) to indicate that a value is stored. We can replace all tests for batteryVoltageAvailable with a test for a non-zero value.

ericklein, 2023-02-24:
bool batteryVoltageAvailable replaced with hardwareData.batteryVoltage > 0 throughout code base. Verification of change now needed.

ericklein, 2023-02-25:
internetAvailable replaced with hardwareData.rssi != 0 throughout code base. Verification of change now needed.

ericklein, 2023-02-27:
testing in process, initial results support issue resolution

Closed 2023-02-27.

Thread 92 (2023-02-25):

rebuild readme.md

ericklein, 2023-02-25:
Update readme.md based on changes and information from supporting material and air quality references.

ericklein, 2023-04-11:
1. Add UI/functionality description section
2. update information to be current and accurate
3. review David's UI changes (RCO2) for relevant changes to AQ readme
4. Add relevant supporting_material (private) to readme (public)

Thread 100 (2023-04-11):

Use conditional defines in config.h for SCREEN variables

ericklein, 2023-04-11:
Use conditional defines to automatically switch between MagTag and Featherwing epd screen support.

ericklein, 2023-04-11:
This is working in gpio_wakeup branch, might want to pull this support out into main independent of gpio pin wakeup support.

ericklein, 2023-05-30:
this is also in ek_fixes, which will be promoted to main before gpio_wakeup

Closed 2023-05-30.

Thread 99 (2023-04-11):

#define support for non SCD40 hardware

ericklein, 2023-04-11:
Allow for config.h only selection of supported environment sensors. SCD40 support is explicitly set via #define, and BME280 support is default if SCD40 is not defined. To support AHT2X sensors, you have to comment and uncomment code in the globals section of air_quality.ino

ericklein, 2023-05-30:
this is fixed in ek_fixes, which will be tested and promoted. Added a #BME680 and #AHTXX to support those sensors explictly. Those sensors, outside of their hardware include, use the same code, based on Adafruit Unified Sensor, to read data.

Closed 2023-05-30.

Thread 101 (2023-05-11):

Reported temp/humidity #s seem suspect

ericklein, 2023-05-11:
Seeing temp and humidity values in  MQTT (influxdb) that are well above what I'm seeing on the screen, more than a 5-6 sample average should be. +13 temp, +7% humidity. Check the algo

ericklein, 2023-10-03:
averages were dividing by SAMPLE_SIZE although samples were stored starting at zero, so denominator off by 1. Fixed.

Closed 2023-10-03.

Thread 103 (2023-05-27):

batteryRead doesn't set hardwareData.battery to 0 if hardware not detected

ericklein, 2023-05-27:

ericklein, 2023-11-04:
.batteryVoltage is set to 0 early in setup(). If lc.read() fails, it will still be at 0. Same holds true with the software detection routine.

Closed 2023-11-04.

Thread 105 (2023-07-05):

Display charging icon when attached to USB cable

ericklein, 2023-07-05:
Our target platform includes charging the battery when connected to USB. AQ should detect this and modify the battery gauge to indicate charging status. This requires additional hardware.

ericklein, 2023-09-21:
this does not always require additional hardware. This change has been in implemented in ericklein/battery_check

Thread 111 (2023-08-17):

Log battery temperature on all AQ units

ericklein, 2023-08-17:
As the units come in for software upgrade, add the 10K thermistor.

Add battery temperature to hardwareData struct and log it via appropriate network endpoints.

Closed 2024-11-25.

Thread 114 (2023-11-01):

Add thermistor support to LC709203F code`

ericklein, 2023-11-01:
Thermistors in-place on all deployed LC709203F units, allowing for battery temperature capture.

ericklein, 2024-11-25:
thermistors added to all AQ units in the field. preliminary software support is added (commented out), but reporting has not been added.

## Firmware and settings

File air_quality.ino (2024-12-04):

/*
  Project:      air_quality
  Description:  Regularly sample, display, and log temperature, humidity, and co2 levels
*/

// hardware and internet configuration parameters
#include "config.h"
// private credentials for network, MQTT, weather provider
#include "secrets.h"

// read/write to ESP32 persistent storage
#include <Preferences.h>
Preferences nvStorage;

// accumulating sensor readings
// IMPROVEMENT: nvStorageRead() should return these locally
float accumulatingTempF;
float accumulatingHumidity;

// environment sensor data
typedef struct {
  float ambientTemperatureF;    // range -10C to 60C
  float ambientHumidity;        // RH [%], range 0 to 100
  uint16_t  ambientCO2;         // ppm, range 400 to 2000
} envData;
envData sensorData;

// stores CO2 sample values for sparkline
uint16_t co2Samples[sensorSampleSize];

// hardware status data
typedef struct {
  float batteryPercent;
  float batteryVoltage;
  // float batteryTemperatureF;
  uint8_t rssi;
} hdweData;
hdweData hardwareData; 

// OpenWeatherMap Current data
typedef struct {
  // float lon;              // "lon": 8.54
  // float lat;              // "lat": 47.37
  // uint16_t weatherId;     // "id": 521
  // String main;            // "main": "Rain"
  // String description;     // "description": "shower rain"
  String icon;               // "icon": "09d"
  float tempF;                // "temp": 90.56, in F (API request for imperial units)
  // uint16_t pressure;      // "pressure": 1013, in hPa
  uint16_t humidity;         // "humidity": 87, in RH%
  // float tempMin;          // "temp_min": 89.15
  // float tempMax;          // "temp_max": 92.15
  // uint16_t visibility;    // visibility: 10000, in meters
  // float windSpeed;        // "wind": {"speed": 1.5}, in meters/s
  // float windDeg;          // "wind": {deg: 226.505}
  // uint8_t clouds;         // "clouds": {"all": 90}, in %
  // time_t observationTime; // "dt": 1527015000, in UTC
  // String country;         // "country": "CH"
  // time_t sunrise;         // "sunrise": 1526960448, in UTC
  // time_t sunset;          // "sunset": 1527015901, in UTC
  String cityName;           // "name": "Zurich"
  // time_t timezone;        // shift in seconds from UTC
} OpenWeatherMapCurrentData;
OpenWeatherMapCurrentData owmCurrentData;  // global variable for OWM current data

// OpenWeatherMap Air Quality data
typedef struct {
  // float lon;    // "lon": 8.54
  // float lat;    // "lat": 47.37
  uint16_t aqi;  // "aqi": 2  [European standards body value]
  // float co;     // "co": 453.95, in μg/m3
  // float no;     // "no": 0.47, in μg/m3
  // float no2;    // "no2": 52.09, in μg/m3
  // float o3;     // "o3": 17.17, in μg/m3
  // float so2;    // "so2": 7.51, in μg/m3
  float pm25;  // "pm2.5": 8.04, in μg/m3
  // float pm10;   // "pm10": 9.96, in μg/m3
  // float nh3;    // "nh3": 0.86, in μg/m3
} OpenWeatherMapAirQuality;
OpenWeatherMapAirQuality owmAirQuality;  // global variable for OWM current data

#ifndef HARDWARE_SIMULATE
  // instanstiate SCD4X hardware object
  #include <SensirionI2CScd4x.h>
  SensirionI2CScd4x co2Sensor;

  // battery voltage sensor
  #include <Adafruit_LC709203F.h>
  Adafruit_LC709203F lc;

  // WiFi support
  #if defined(ESP8266)
    #include <ESP8266WiFi.h>
  #elif defined(ESP32)
    #include <WiFi.h>
  #endif
  #include <HTTPClient.h>
  WiFiClient client;   // used by OWM and MQTT
#endif

// e-paper display support
#include <GxEPD2_BW.h>
GxEPD2_BW<GxEPD2_290_T5D, GxEPD2_290_T5D::HEIGHT> display(GxEPD2_290_T5D(EPD_CS, EPD_DC, EPD_RESET, EPD_BUSY)); // GDEW029T5D 128x296, UC8151D

#include "Fonts/meteocons20pt7b.h"
#include "Fonts/meteocons16pt7b.h"
#include "Fonts/meteocons12pt7b.h"

#include <Fonts/FreeSans9pt7b.h>
#include <Fonts/FreeSans12pt7b.h>
#include <Fonts/FreeSans18pt7b.h>

// Special glyphs for the UI
#include "Fonts/glyphs.h"

// Libraries needed to access Open Weather Map
#include "ArduinoJson.h"  // Needed by OWM retrieval routines

// internet services if using network data endpoints
#if defined(MQTT) || defined(INFLUX) || defined(HASSIO_MQTT) || defined(DWEET)
  // NTP setup using Esperiff library
  #include <time.h>
#endif

#ifdef INFLUX
extern boolean post_influx(uint16_t co2, float temperatureF, float humidity, float batteryVoltage, uint8_t rssi);
#endif

#ifdef DWEET
extern void post_dweet(uint16_t co2, float temperatureF, float humidity, float batteryVoltage, uint8_t rssi);
#endif

#ifdef MQTT
  #include <Adafruit_MQTT.h>
  #include <Adafruit_MQTT_Client.h>
  Adafruit_MQTT_Client aq_mqtt(&client, MQTT_BROKER, MQTT_PORT, DEVICE_ID, MQTT_USER, MQTT_PASS);
  
  extern bool mqttDeviceWiFiUpdate(uint8_t rssi);
  extern bool mqttDeviceBatteryUpdate(float batteryVoltage);
  extern bool mqttSensorTemperatureFUpdate(float temperatureF);
  extern bool mqttSensorHumidityUpdate(float humidity);
  extern bool mqttSensorCO2Update(uint16_t co2);
  #ifdef HASSIO_MQTT
    extern void hassio_mqtt_publish(uint16_t co2, float temperatureF, float humidity, float batteryVoltage);
  #endif
#endif

void setup()
// One time run of code, then deep sleep
{
// handle Serial first so debugMessage() works
#ifdef DEBUG
  Serial.begin(115200);
  // wait for serial port connection
  while (!Serial);
  debugMessage("starting Air Quality, Device ID: " + String(DEVICE_ID), 1);
  debugMessage(String("SCD4x sample interval is ") + sensorSampleInterval + " seconds", 1);
  #if defined(MQTT) || defined(INFLUX) || defined(HASSIO_MQTT)
    debugMessage(String("Number of samples before reporting is ") + sensorSampleSize, 1);
  #endif
  debugMessage(String("Internet service reconnect delay is ") + networkConnectAttemptInterval + " seconds", 2);
  #ifdef DWEET
    debugMessage("Dweet device: " + String(DWEET_DEVICE), 2);
  #endif
#endif

// generate random numbers for every boot cycle
randomSeed(analogRead(0));

powerI2CEnable();

// initialize e-paper first to display hardware error messages
display.init(115200);
debugMessage("epd initialized", 1);
display.setTextWrap(false);
display.setRotation(displayRotation);

// Initialize SCD4X
if (!sensorCO2Init()) {
  screenAlert("No SCD4X");
  // This error often occurs right after a firmware flash and reset.
  // Hardware deep sleep typically resolves it, so quickly cycle the hardware
  powerDisable(hardwareRebootInterval);
}

  // Environmental sensor available, so fetch values
  if (!sensorCO2Read()) {
    // hard coded for SCD40 as there is no way to read error condition on other sensors
    debugMessage("SCD40 returned no/bad data", 1);
    screenAlert("SCD40 read issue");
    powerDisable(hardwareRebootInterval);
  }
  uint8_t sampleCounter = nvStorageRead();
  sampleCounter++;
  debugMessage(String("Sample count: ") + (sampleCounter) + " of " + sensorSampleSize,1);

  accumulatingTempF += sensorData.ambientTemperatureF;
  accumulatingHumidity += sensorData.ambientHumidity;

  if (sampleCounter < sensorSampleSize)
  // add to the accumulating, intermediate sensor values and sleep device
  {
    nvStorageWrite(sampleCounter, accumulatingTempF, accumulatingHumidity, sensorData.ambientCO2);
    powerDisable(sensorSampleInterval);
  }

  // this code only executes if sampleCounter == sensorSampleSize
  // average values, send to network endpoint if possible, display values, reset values, then sleep device

  float averageTempF = accumulatingTempF / sampleCounter;
  float averageHumidity = accumulatingHumidity / sampleCounter;

  // aggregate stored, rolling CO2 values
  uint16_t accumulatingCO2 = 0;
  for (uint8_t loop = 0; loop < sensorSampleSize; loop++) {
    accumulatingCO2 += co2Samples[loop];
  }
  // add in most CO2 recent sample then average
  uint16_t averageCO2 = (accumulatingCO2 + sensorData.ambientCO2) / sampleCounter;
  debugMessage(String("Averaged values Temp:") + averageTempF + "F, Humidity:" + averageHumidity + ", CO2:" + averageCO2, 1);

  if (!batteryRead(batteryReadsPerSample))
    hardwareData.batteryVoltage = 0;

  // Setup network connection specified in config.h
  networkConnect();

  networkGetTime(networkTimeZone);

  // Get local weather and air quality info from Open Weather Map
  if (!OWMCurrentWeatherRead()) {
    owmCurrentData.tempF = 10000;
  }

  if (!OWMAirPollutionRead()) {
    owmAirQuality.aqi = 10000;
  }

  String upd_flags = "";  // indicates whether network endpoint publish(es) succeeded
  if (hardwareData.rssi != 0) {
    #ifdef MQTT
        if ((mqttSensorTemperatureFUpdate(averageTempF)) && (mqttSensorHumidityUpdate(averageHumidity)) && (mqttSensorCO2Update(averageCO2)) && (mqttDeviceWiFiUpdate(hardwareData.rssi)) && (mqttDeviceBatteryUpdate(hardwareData.batteryVoltage))) {
          upd_flags += "M";
          debugMessage("MQTT publish successful",1);
        }
        else
          debugMessage("One or more MQTT publishes unsuccessful",1);
        #ifdef HASSIO_MQTT
              debugMessage("Establishing MQTT for Home Assistant", 1);
              // Either configure sensors in Home Assistant's configuration.yaml file
              // directly or attempt to do it via MQTT auto-discovery
              // hassio_mqtt_setup();  // Config for MQTT auto-discovery
              hassio_mqtt_publish(sensorData.ambientCO2, sensorData.ambientTemperatureF, sensorData.ambientHumidity, hardwareData.batteryVoltage);
        #endif
    #endif

    #ifdef DWEET
        post_dweet(averageCO2, averageTempF, averageHumidity, hardwareData.batteryVoltage, hardwareData.rssi);
        upd_flags += "D";
    #endif

    #ifdef INFLUX
        // Returns true if successful
        if (post_influx(averageCO2, averageTempF, averageHumidity, hardwareData.batteryVoltage, hardwareData.rssi)) {
          upd_flags += "I";
          debugMessage("Influx publish successful",1);
        }
        else
          debugMessage("Influx publish unsuccessful",1);
    #endif

    if (upd_flags == "") {
      // network endpoints not updated but we have network time
      screenInfo(dateTimeString("short"));
    } 
    else {
      // network endpoints updated and we have network time
      screenInfo("[+" + upd_flags + "] " + dateTimeString("short"));
    }
  } 
  else {
    // no internet connection, update screen with sensor data only
    #ifdef DEBUG
        screenInfo("DEBUG + no Internet");
    #else
        screenInfo("");
    #endif
  }
  //reset nvStorage values for next recording period
  nvStorageWrite(0, 0, 0, 0);
  powerDisable(sensorSampleInterval);
}

void loop() {}

void debugMessage(String messageText, uint8_t messageLevel)
// wraps Serial.println as #define conditional
{
#ifdef DEBUG
  if (messageLevel <= DEBUG) {
    Serial.println(messageText);
    Serial.flush();  // Make sure the message gets output (before any sleeping...)
  }
#endif
}

bool OWMCurrentWeatherRead()
// Gets Open Weather Map Current Weather data
{
  // compile only if screen available
  #ifdef HARDWARE_SIMULATE
    OWMCurrentWeatherSimulate();
    return true;
  #else
    if (hardwareData.rssi != 0) // internet connectivity?
    {
      String jsonBuffer;

      // Get local weather conditions
      String serverPath = String(OWM_SERVER) + OWM_WEATHER_PATH + OWM_LAT_LONG + "&units=imperial" + "&APPID=" + OWM_KEY;

      jsonBuffer = networkHTTPGETRequest(serverPath.c_str());
      debugMessage("Raw JSON from OWM Current Weather feed", 2);
      debugMessage(jsonBuffer, 2);
      if (jsonBuffer == "HTTP GET error") {
        return false;
      }

      DynamicJsonDocument doc(2048);

      DeserializationError error = deserializeJson(doc, jsonBuffer);

      if (error) {
        debugMessage(String("deserializeJson failed with error message: ") + error.c_str(), 1);
        return false;
      }

      uint8_t code = (uint8_t)doc["cod"];
      if (code != 200) {
        debugMessage(String("OWM error: ") + (const char *)doc["message"], 1);
        return false;
      }

      // owmCurrentData.lat = (float) doc["coord"]["lat"];
      // owmCurrentData.lon = (float) doc["coord"]["lon"];

      // owmCurrentData.main = (const char*) doc["weather"][0]["main"];
      // owmCurrentData.description = (const char*) doc["weather"][0]["description"];
      owmCurrentData.icon = (const char *)doc["weather"][0]["icon"];

      owmCurrentData.cityName = (const char *)doc["name"];
      // owmCurrentData.visibility = (uint16_t) doc["visibility"];
      // owmCurrentData.timezone = (time_t) doc["timezone"];

      // owmCurrentData.country = (const char*) doc["sys"]["country"];
      // owmCurrentData.observationTime = (time_t) doc["dt"];
      // owmCurrentData.sunrise = (time_t) doc["sys"]["sunrise"];
      // owmCurrentData.sunset = (time_t) doc["sys"]["sunset"];

      owmCurrentData.tempF = (float)doc["main"]["temp"];
      // owmCurrentData.pressure = (uint16_t) doc["main"]["pressure"];
      owmCurrentData.humidity = (uint8_t)doc["main"]["humidity"];
      // owmCurrentData.tempMin = (float) doc["main"]["temp_min"];
      // owmCurrentData.tempMax = (float) doc["main"]["temp_max"];

      // owmCurrentData.windSpeed = (float) doc["wind"]["speed"];
      // owmCurrentData.windDeg = (float) doc["wind"]["deg"];
      debugMessage(String("OWM Current Weather: ") + owmCurrentData.tempF + "F, " + owmCurrentData.humidity + "% RH", 1);
      return true;
    }
  #endif
  return false;
}

bool OWMAirPollutionRead()
// stores local air pollution info from Open Weather Map in environment global
{
  #ifdef HARDWARE_SIMULATE
    OWMAirPollutionSimulate();
    return true;
  #else
    // check for internet connectivity
    if (hardwareData.rssi != 0)
    {
      String jsonBuffer;

      // Get local AQI
      String serverPath = String(OWM_SERVER) + OWM_AQM_PATH + OWM_LAT_LONG + "&APPID=" + OWM_KEY;

      jsonBuffer = networkHTTPGETRequest(serverPath.c_str());
      debugMessage("Raw JSON from OWM Air Pollution feed", 2);
      debugMessage(jsonBuffer, 2);
      if (jsonBuffer == "HTTP GET error") {
        return false;
      }

      DynamicJsonDocument doc(384);

      DeserializationError error = deserializeJson(doc, jsonBuffer);
      if (error) {
        debugMessage(String("deserializeJson failed with error message: ") + error.c_str(), 1);
        return false;
      }

      // owmAirQuality.lon = (float) doc["coord"]["lon"];
      // owmAirQuality.lat = (float) doc["coord"]["lat"];
      JsonObject list_0 = doc["list"][0];
      owmAirQuality.aqi = list_0["main"]["aqi"];
      JsonObject list_0_components = list_0["components"];
      // owmAirQuality.co = (float) list_0_components["co"];
      // owmAirQuality.no = (float) list_0_components["no"];
      // owmAirQuality.no2 = (float) list_0_components["no2"];
      // owmAirQuality.o3 = (float) list_0_components["o3"];
      // owmAirQuality.so2 = (float) list_0_components["so2"];
      owmAirQuality.pm25 = (float)list_0_components["pm2_5"];
      // owmAirQuality.pm10 = (float) list_0_components["pm10"];
      // owmAirQuality.nh3 = (float) list_0_components["nh3"];
      debugMessage(String("OWM Air Pollution: ") + owmAirQuality.aqi + " AQI, " + owmAirQuality.pm25 + "ppm PM2.5", 1);
      return true;
    }
    return false;
  #endif
}

void screenAlert(String messageText)
// Display error message centered on screen
{
  debugMessage(String("screenAlert '") + messageText + "' start",1);

  int16_t x1, y1;
  uint16_t width, height;

  display.setTextColor(GxEPD_BLACK);
  display.setFont(&FreeSans12pt7b);
  display.getTextBounds(messageText.c_str(), 0, 0, &x1, &y1, &width, &height);
  if (width >= display.width()) {
    debugMessage("ERROR: screenAlert message text too long", 1);
  }

  display.setFullWindow();
  display.firstPage();
  do
  {
    display.fillScreen(GxEPD_WHITE);
    display.setCursor(display.width() / 2 - width / 2, display.height() / 2 + height / 2);
    display.print(messageText);
  }
  while (display.nextPage());

  debugMessage("screenAlert() end", 1);
}

void screenInfo(String messageText)
// Display environmental information on screen
{
  // screen layout assists
  const uint16_t xMargins = 5;
  const uint16_t xOutdoorMargin = ((display.width() / 2) + xMargins);
  const uint16_t yMargins = 2;
  const uint16_t yCO2 = 20;
  const uint16_t ySparkline = 40;
  const uint16_t yTemperature = 100;
  const uint16_t yStatus = (display.height() * 7 / 8);
  const uint16_t sparklineHeight = 40;
  const uint16_t batteryBarWidth = 28;
  const uint16_t batteryBarHeight = 10;
  const uint16_t wifiBarWidth = 3;
  const uint16_t wifiBarHeightIncrement = 2;
  const uint16_t wifiBarSpacing = 5;

  debugMessage("Starting screenInfo refresh", 1);
  display.setTextColor(GxEPD_BLACK);
  display.setFullWindow();
  display.firstPage();
  do
  {
    display.fillScreen(GxEPD_WHITE);
    // borders
    display.drawFastHLine(0, yStatus, display.width(), GxEPD_BLACK);
    // splitting sensor vs. outside values
    display.drawFastVLine((display.width() / 2), 0, yStatus, GxEPD_BLACK);

    // screen helper routines
    // draws battery in the lower right corner, -3 in first parameter accounts for battery nub
    screenHelperBatteryStatus((display.width() - xMargins - batteryBarWidth - 3), (display.height() - yMargins - batteryBarHeight), batteryBarWidth, batteryBarHeight);

    // -70 moves it to the left of the battery display
    screenHelperWiFiStatus((display.width() - xMargins - 70), (display.height() - yMargins), wifiBarWidth, wifiBarHeightIncrement, wifiBarSpacing);

    // draws any status message in the lower left corner. -8 in the first parameter accounts for fixed font height
    screenHelperStatusMessage(xMargins, (display.height() - yMargins - 8), messageText);

    // display sparkline
    screenHelperSparkLine(xMargins, ySparkline, ((display.width() / 2) - (2 * xMargins)), sparklineHeight);

    // Indoor
    // CO2 level

    // main line
    display.setFont(&FreeSans12pt7b);
    display.setCursor(xMargins, yCO2);
    display.print("CO");
    display.setCursor(xMargins + 50, yCO2);
    display.print(": " + String(warningLabels[co2Range(sensorData.ambientCO2)]));
    display.setFont(&FreeSans9pt7b);
    display.setCursor(xMargins + 35, (yCO2 + 10));
    display.print("2");
    // value line
    display.setFont();
    display.setCursor((xMargins + 88), (yCO2 + 7));
    display.print("(" + String(sensorData.ambientCO2) + ")");

    // Indoor temp
    display.setFont(&FreeSans12pt7b);
    display.setCursor(xMargins, yTemperature);
    display.print(String((uint8_t)(sensorData.ambientTemperatureF + .5)));
    display.setFont(&meteocons12pt7b);
    display.print("+");

    // Indoor humidity
    display.setFont(&FreeSans12pt7b);
    display.setCursor(xMargins + 60, yTemperature);
    display.print(String((uint8_t)(sensorData.ambientHumidity + 0.5)));
    // original icon ratio was 5:7?
    display.drawBitmap(xMargins + 90, yTemperature - 21, epd_bitmap_humidity_icon_sm4, 20, 28, GxEPD_BLACK);

    // Outside
    // do we have OWM Current data to display?
    if (owmCurrentData.tempF != 10000) {
      // location label
      display.setFont();
      display.setCursor((display.width() * 5 / 8), yMargins);
      display.print(owmCurrentData.cityName);

      // Outside temp
        display.setFont(&FreeSans12pt7b);
        display.setCursor(xOutdoorMargin, yTemperature);
        display.print(String((uint8_t)(owmCurrentData.tempF + 0.5)));
        display.setFont(&meteocons12pt7b);
        display.print("+");

      // Outside humidity
      display.setFont(&FreeSans12pt7b);
      display.setCursor(xOutdoorMargin + 60, yTemperature);
      display.print(String((uint8_t)(owmCurrentData.humidity + 0.5)));
      display.drawBitmap(xOutdoorMargin + 90, yTemperature - 21, epd_bitmap_humidity_icon_sm4, 20, 28, GxEPD_BLACK);

      // weather icon
      String weatherIcon = OWMtoMeteoconIcon(owmCurrentData.icon);
      // if getMeteoIcon doesn't have a matching symbol, skip display
      if (weatherIcon != ")") {
        // display icon
        display.setFont(&meteocons20pt7b);
        display.setCursor((display.width() * 17 / 20), (display.height() / 2) + 10);
        display.print(weatherIcon);
      }
    }

    // Outside air quality index (AQI) + PM25 value
    if (owmAirQuality.aqi != 10000) {
      // main line
      display.setFont(&FreeSans9pt7b);
      display.setCursor(xOutdoorMargin, ySparkline - 5);
      display.print(OWMAQILabels[(owmAirQuality.aqi-1)]);
      display.print(" AQI");
      // value line
      display.setFont();
      display.setCursor((xOutdoorMargin + 20), (ySparkline + 3));
      display.print(String(uint16_t(owmAirQuality.pm25+.5)) + " pm25");
    }
  }
  while (display.nextPage());

  debugMessage("screenInfo refresh complete", 1);
}

void screenHelperStatusMessage(uint16_t initialX, uint16_t initialY, String messageText)
// helper function for screenXXX() routines that draws a status message
// uses system default font, so text drawn x+,y+ from initialX,Y
{
  // IMPROVEMENT : Screen dimension boundary checks for function parameters
  display.setFont();  // resets to system default monospace font (6x8 pixels)
  display.setCursor(initialX, initialY);
  display.print(messageText);
  debugMessage(String("screenHelperStatusMessage() displayed: ") + messageText + " at X:" + initialX + ",Y:" + initialY, 2);
}
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

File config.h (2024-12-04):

/*
  Project Name:   air_quality
  Description:    public (non-secret) configuration data
*/	

// Configuration Step 1: Create and/or configure secrets.h. Use secrets_template.h as guide to create secrets.h

// Configuration Step 2: Set debug message output
// comment out to turn off; 1 = summary, 2 = verbose
#define DEBUG 2

// Configuration Step 3: simulate WiFi and sensor hardware,
// returning random but plausible values
// comment out to turn off
// #define HARDWARE_SIMULATE

// Configuration Step 4: Set network data endpoints
 // #define MQTT 		// log sensor data to MQTT broker
// #define HASSIO_MQTT  // And, if MQTT enabled, with Home Assistant too?
// #define DWEET // Post sensor readings to dweet.io
// #define INFLUX 	// Log data to remote InfluxDB server

// Configuration Step 5: Set battery size, if applicable
// If LC709203F detected on i2c, define battery pack based on settings curve from datasheet
// #define BATTERY_APA 0x08 // 100mAH
// #define BATTERY_APA 0x0B // 200mAH
 // #define BATTERY_APA 0x10 // 500mAH
// #define BATTERY_APA 0x19 // 1000mAH
// #define BATTERY_APA 0x1D // 1200mAH
#define BATTERY_APA 0x2D // 2000mAH
// #define BATTERY_APA 0x32 // 2500mAH
// #define BATTERY_APA 0x36 // 3000mAH

// Configuration variables that change rarely

// Time
// NTP time parameters
const String networkNTPAddress = "pool.ntp.org";
const String networkTimeZone = "PST8PDT,M3.2.0,M11.1.0"; // America/Los_Angeles
const String weekDays[7] = { "Sunday", "Monday", "Tuesday", "Wednesday", "Thursday", "Friday", "Saturday" };

// network endpoints
#ifdef INFLUX  
	// Specify Measurement to use with InfluxDB for sensor and device info
	const String influxEnvMeasurement = "weather";  // Used for environmental sensor data
	const String influxDevMeasurement =  "device";   // Used for logging AQI device data (e.g. battery)
#endif

#ifdef DWEET
	// Post data to the internet via dweet.io.  Set DWEET_DEVICE to be a
	// unique name you want associated with this reporting device, allowing
	// data to be easily retrieved through the web or Dweet's REST API.
	#define DWEET_HOST "dweet.io"   // Typically dweet.io
	#define DWEET_DEVICE "makerhour-airquality"  // Must be unique across all of dweet.io
#endif

// Open Weather Map (OWM)
#define OWM_SERVER			"http://api.openweathermap.org/data/2.5/"
#define OWM_WEATHER_PATH	"weather?"
#define OWM_AQM_PATH		"air_pollution?"
const String OWMAQILabels[5] = {"Good", "Fair", "Moderate", "Poor", "Very Poor"};

// Sample and reporting intervals
#ifdef DEBUG
	// time between samples in seconds
	const uint16_t sensorSampleInterval = 60;
	// number of samples to average. this is also the # of uint_16 CO2 samples saved to nvStorage, so limit this
  const uint8_t sensorSampleSize = 4;
#else
	const uint16_t sensorSampleInterval = 300;
  const uint8_t sensorSampleSize = 6;
#endif

// warnings
const String warningLabels[4]={"Good", "Fair", "Poor", "Bad"};
// Subjective color scheme using 16 bit ('565') RGB colors
// const uint16_t warningColor[4] = {
//   0x07E0, // Green = "Good"
//   0xFFE0, // Yellow = "Fair"
//   0xFD20, // Orange = "Poor"
//   0xF800  // Red = "Bad"
//   };

// Hardware

// Simulation boundary values
#ifdef HARDWARE_SIMULATE
  const uint16_t sensorTempMinF =       1400; // divided by 100.0 to give floats
  const uint16_t sensorTempMaxF =       14000;
  const uint16_t sensorHumidityMin =    0; // RH%, divided by 100.0 to give float
  const uint16_t sensorHumidityMax =    10000;

  const uint8_t OWMAQIMin = 1;  // https://openweathermap.org/api/air-pollution
  const uint8_t OWMAQIMax = 5;

  const uint16_t OWMPM25Min = 0;  // will be divided by 100.0 to give float
  const uint32_t OWMPM25Max = 10000; // will be divided by 100.0 to give float

  const uint16_t batterySimVoltageMin = 370; // will be divided by 100.0 to give floats
  const uint16_t batterySimVoltageMax = 410;

  const uint8_t networkRSSIMin = 30;
  const uint8_t networkRSSIMax = 90;
#endif

// CO2 from SCD4x
// CO2 value thresholds for labeling
const uint16_t co2Fair = 800;
const uint16_t co2Poor = 1200;
const uint16_t co2Bad = 2000;

const uint16_t sensorCO2Min =      400;   // in ppm
const uint16_t sensorCO2Max =      2000;  // in ppm
const uint8_t sensorTempCOffset = 0;     // in Celcius

// particulates (pm1, pm2.5, pm4, pm10) from SEN5x
// CO2 value thresholds for labeling
const uint16_t pmFair = 25;
const uint16_t pmPoor = 50;
const uint16_t pm2Bad = 150;

// Sleep time in seconds if hardware error occurs
const uint8_t hardwareRebootInterval = 10;
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

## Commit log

2020-09-01 Version 1
    First, unoptimized version based on merged sample code for sensors, SD. Ethernet code NOT working.
    [air_quality.ino]
2020-09-11 Crash fix
    fixed crash after one main() iteration
    [air_quality.ino]
2020-10-02 initial MQTT support
    initial MQTT support and partial WiFi refactoring. Code stability is questionable
    [air_quality.ino]
2020-11-11 multiple fixes
    WiFi support, consolidated MQTT code, numerous bug fixes. See readme.md for details.
    [air_quality.ino]
2020-11-14 Error handling
    Code cleanup, improved error handling, MQTT changes
    [air_quality.ino]
2020-11-29 intermediate changes
    code changes needed to build a new sensor for bug reproduction
    [air_quality.ino]
2021-01-24 error handling
    accumulated changes for error handling
    [air_quality.ino]
2021-08-23 first version
    Add the room name where the samples are captured into the data stream rather than as hard coded via #define
2021-08-25 final branch fixes
    Code lightly tested and in production
    [air_quality.ino]
2021-09-02 mqttconnect error handling
    083021
    - removed while(1) for mqttconnect()
    - #DEBUG log formatting fixes
    - Time fixes
    - [I][P3]082521: quasi clock generates two messages every 10 seconds instead of one -> dependent on code and processor, # of messages dependent on times through loop within the 1ms
    - [Q]100220: time; Every five minutes we are generating a "Transmitting NTP request"? -> Expected behavior, any time a timelib function is used, timelib is checking and potentially synching to time provider. In this case, a time string was being generated associated with each mqtt log entry, causing the sync
    - [I][P3]111020: time; How do we better handle Daylight vs. Standard time? -> Switched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
    [air_quality.ino]
2021-09-02 Move CO2 to private branch
    moving CO2 code to private branch as it does not work accurately and needs debug
    [air_quality.ino]
2021-09-03 switch to AHT20
    switch to AHT20 with its i2c comm plus more redaction of SGP30, proximity related material
2021-09-10 WiFi, MQTT bug fixes
    primarily bug fixes and logging improvements in the #MQTTLOG and #WIFI code paths.
    [air_quality.ino]
2021-09-14 ESP32 deep sleep, EPD UI
2021-09-14 issue logging
    cleanup of [I], [FR], and [Q] in readme
    [air_quality.ino]
2021-09-16 field unit release 1
    Device outside of lab for testing. known issues logged
    [air_quality.ino]
2021-09-16 P1 bug fixes
    Solved significant MQTT issue, improved screen handling
    [air_quality.ino]
2021-10-09 Battery level indicator
    Initial battery level indicator support. I believe the code is working properly but need to verify as the battery readouts I'm getting from sample and my code are incorrect
2021-11-06 Battery level display
    conditional battery level display via LC709203F
2021-11-15 Conditional code for co2
    Fixes for c02 code and ARM vs. ESP32 log times
    [air_quality.ino]
2022-01-02 power management fix?
    Adding code not likely to improve reported battery drain issue, but should probably be there
    [air_quality.ino]
2022-01-03 SCD40 power management
    stopping SCD40 before deepSleep()
2022-02-05 Bug fixes
    bug fixes
    [air_quality.ino, config.h]
2022-02-10 compiling
    fixes for proper compilation
    [air_quality.ino, config.h]
2022-02-11 MQTTLOG reimplemented
    MQTTLOG put back in. Removing it was a use case oversight.
2022-02-11 MQTT logic fix
    incorrect error detection, need to use AND not OR
    [air_quality.ino]
2022-03-14 bug fixes and dateTimeString()
    bug fixes. removed NTP code. added NTPClient library support. rewrote zuluDateTimeString() as dataTimeString() with support for NTPClient and new user friendly output.
    [air_quality.ino, config.h]
2022-03-15 security issue
    moving lat/long info to secrets.h, small refactor in infoScreen()
    [air_quality.ino, config.h]
2022-03-21 first version
    Test code for validation and bug fixes
    [air_quality.ino, config.h]
2022-03-22 #define testing
    Testing the averaging code and different #define parameters yielded many bug fixes and subtle debug string improvements
    [air_quality.ino, config.h]
2022-04-18 move initScreen to post sensor read
    move screen initialization after sensor reads to save time/energy when device is only awake to get an intermediate sensor read. Plus some hygiene improvements.
2022-04-22 Publish device data to Influx (new)
2022-05-06 Headless, CO2 logic, NAN filtering
    Fixes to re-enable headless build, fixes to support sensors without CO2 (e.g. CO2=10000), NAN filtering for values bring written into nv storage, and interim change to AQ_Network::httpGETRequest HTTP return code handling
    [air_quality.ino, config.h]
2022-05-12 SAMPLE_INTERVAL for DEBUG
    Adding different SAMPLE_INTERVAL values for DEBUG vs. production
2022-05-13 getWeather() logic fix
    getWeather() fix when internet is not available, fix to SAMPLE_SIZE reset, aesthetic change to alertScreen().
    [air_quality.ino]
2022-05-13 Screen initalization changes
    screenAlert() needs display.begin() as a precedent call. Also, continuing to see cases where EPD_BUSY can be -1 and the screen works and cases where it doesn't work. So moving to EPD_BUSY = 5.
    [air_quality.ino, config.h]
2022-05-13 MagTag PIN assignments
    I changed the MagTag EPD PIN configuration and promoted it to master without adequate testing. Reverting to old, tested values. This should eliminate bad boot into a purple blinking neopixel state.
    [air_quality.ino]
2022-05-26 zero accumulating data between sample sets
    zero accumulating data between sample sets.
2022-05-26 submitted to testing
    This version is in active testing on multiple units. New UI for infoScreen and nv storage is zeroed after each sample set is complete
2022-06-04 Fixed Dweet-related compiler errors
    [air_quality.ino]
2022-06-09 MQTT battery voltage, RSSI
    Battery voltage and RSSI posted to MQTT. Ethernet code compile issue fixed. WiFi connect attempt macro moved to config.h
    [air_quality.ino, config.h]
2022-06-10 SCD40 improvements, new messageText
    power management and error handling improvements for SCD40, truncated messageText for infoScreen
    [air_quality.ino, config.h]
2022-06-11 Update config.h
    MQTT PUB_TOPICs added for RSSI and battery voltage
2022-06-11 BME280, AHT2x support
    Consolidating sensor support around the unified Adafruit sensor library currently used with AHT2x. BME280 now read through unified library. SiH7021 support dropped.
2022-06-12 Adafruit unified sensor support
    using Adafruit Unified Sensor library to read both AHTx20 and BME280. Removed SiH7021 support.
2022-07-07 Updates to OWM code
    Improving OWM error handling code, storing OWM data as struct, enabling access to full OWM data fields in preparation for exposing that data in UI
    [air_quality.ino, config.h]
2022-07-07 HTTP Get error handling
    Improved handling of HTTP Get error
    [air_quality.ino]
2022-07-13 MAGTAG + SCD40 as default configuration
    Changed sensor and EPD parameters so the master branch runs on Adafruit MagTag with SCD40.
    To change to other configurations, EPD and sensor specific code has to commented and uncommented. This will be improved in the owm branch, aka next branch to be integrated into master.
2022-09-20 UI changes
    new UI implemented. Cosmetic issues remain.
    [air_quality.ino, config.h]
2022-11-09 MQTT changes
    Fixes for supporting generic MQTT brokers
    [air_quality.ino, config.h]
2022-11-11 change to ESP32 time library
2022-12-09 mqtt fixes
    standardizing connect routines for Internet services.
    [air_quality.ino, config.h]
2023-02-10 timeZone fix and renamed data struct
    [air_quality.ino, config.h]
2023-02-18 improvements from pm25 repo
    Standardization, fixes, and improvements from the pm25 project. No change in functionality
    [air_quality.ino, config.h]
2023-02-19 required merge
    Github issue
    [air_quality.ino, config.h]
2023-02-25 integrating realtimeCO2 screen
    Integrated realtimeCO2 info screen except for sparklines. added screen layout assists. removed internetAvailable and batteryVoltageAvailable and replaced them with checks from the actual hardware data.
    [air_quality.ino]
2023-02-26 works, significant visual errors
    sparkline implemented with test data. this version should show most UI errors to be fixed. The NV read/write for CO2 values needs to be ported from RCO2
    [air_quality.ino, config.h]
2023-02-26 ui parameter adjustments
    fixes to ui element placement, plus a few fixes in debug messages
    [air_quality.ino, config.h]
2023-03-13 sparkline CO2 values to nvStorage
    sparkline co2 values read/write to nvStorage. The sparkline sample set is aligned with SAMPLE_SIZE. Also normalized function names as nounVerb (e.g. batteryRead)
2023-03-14 sparkline DIV/0 error fix
    sparkline DIV/0 error fix and various issues resolved. This version will be integrated to main branch.
    [air_quality.ino, config.h]
2023-05-27 multiple fixes
    Improved conditional code support for sensors, debugMessage has normal and verbose logging, code compiles properly when SCREEN not defined, improved documentation for config.h
    [air_quality.ino, config.h]
2023-05-27 fixes for no screen, no co2 config
    Configuration with no screen and no co2 sensor had not been tested for some time. fixes required that should not impact other configurations.
    completely adopted adafruit unified sensor read API
    [air_quality.ino, config.h]
2023-07-28 porting fix screenHelperWiFiStatus
    porting fix when screenHelperWiFiStatus was moved from pm25 project to AQ
    [air_quality.ino, config.h]
2023-07-28 battery changes from rco2
    improved battery handling code from rco2 project. minor changes to screenHelperWiFiStatus labels
2023-08-09 battery visualization fix
2023-08-09 compile fixes
    minor fixes for compile issues. MQTT and influxdb functionality has been tested.
    [air_quality.ino, config.h]
2023-10-03 critical averaging bug fixed
    averaging bug affecting all output fixed. Minor fixes to debug text found during DEBUG 2 log review.
    [air_quality.ino, config.h]
2023-10-31 tempF label
    changing from temperature to tempF for data endpoints
2023-11-14 fix compile error + screenAlert improvements
    fixed general compile error, fixed code not compiling error with SCREEN not defined, improved screenAlert message text error handling.
    [air_quality.ino, config.h]
2023-12-07 bwr epd support removed
    Very slow refresh rate, so no longer being tested.
    [air_quality.ino, config.h]
2023-12-23 simulate sensor and C variable declaration
    Added code to simulate an environment sensor. Switched from Arduino to C standards for variable type declaration.
2023-12-27 simulate sensor and C variable definition
    Simulate environment sensor code added and converted Arduino variable definitions to C standard.
2024-01-03 simulate sensor complete
    SIMULATE_SENSOR code complete
2024-01-04 inital gx_epd2 commit
    switching from adafruit epd library to gx_epd2. normalizing OWM test values into SIMULATE_SENSOR framework. Code not complete.
2024-01-09 hdwe sim, software battery read, variable names
    hardware_simulate changes, improvements to software battery read algo, and variable name changes for readability
2024-01-11 gx_epd2 support
    epd display driver code changed from Adafruit to gx_epd2. epd pinout changed to free up hardware debugger pins. bug fixes.
    [air_quality.ino, config.h]
2024-10-25 new docs
    Added /supporting material to the build after sanitizing it
    readme.md; reformatted, accurate information, and moved information from Evernote and /supporting material to /readme
    [Case_Bottom_20220220.stl, Case_Top_20220220_2.stl]
2024-11-09 readme updates
    minor readme updates and fixing a #define error that prevents compilation
    [air_quality.ino, config.h]
2024-11-25 initial version
    code complete, testing started. there is a reporting issue with temp_mon that might impact this code.
    [air_quality.ino, config.h]
2024-12-02 bug fixes
    various fixes for loops, mostly driven by change from 0 base to 1 base. readability fixes
    [air_quality.ino, config.h]
2024-12-04 bug fixes
    bug fixes for UI and MagTag SCD40 read. Various debug message improvements. removed code for non-supported MCU boards.
    [air_quality.ino, config.h]
